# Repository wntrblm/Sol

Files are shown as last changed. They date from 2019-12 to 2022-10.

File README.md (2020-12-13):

# Winterbloom Sol

Winterbloom Sol is an open-source Eurorack module. You can find out more at https://wntr.dev/sol.

## License and contributing

The code here is available under the [MIT License](firmware/LICENSE), the hardware designs are available under [CC-BY-SA 4.0](hardware/LICENSE). I welcome contributors, please read the [Code of Conduct](CODE_OF_CONDUCT.md) first. :)

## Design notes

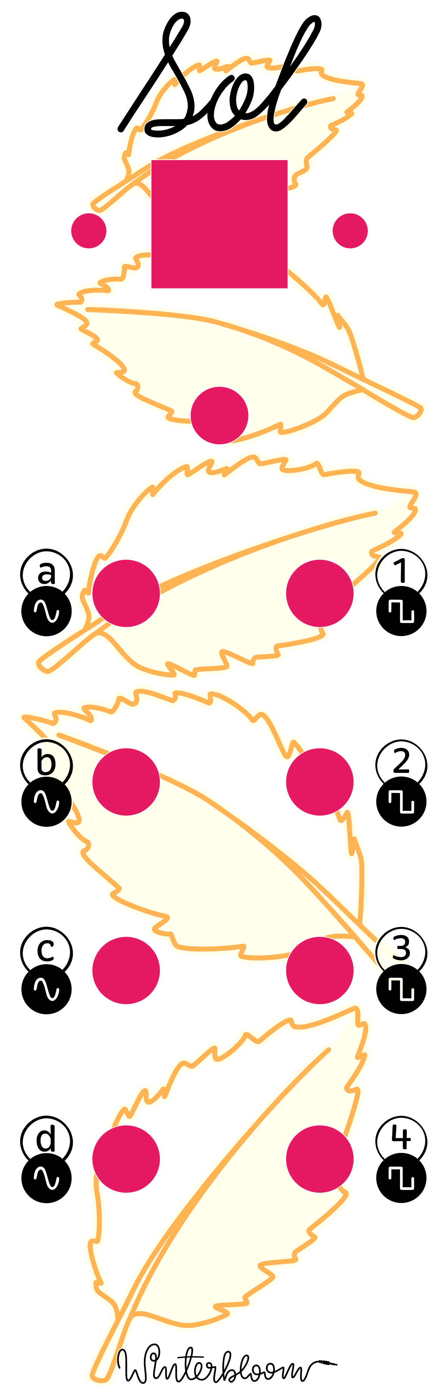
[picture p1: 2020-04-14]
hardware/rev1/panel/panel-texture.png

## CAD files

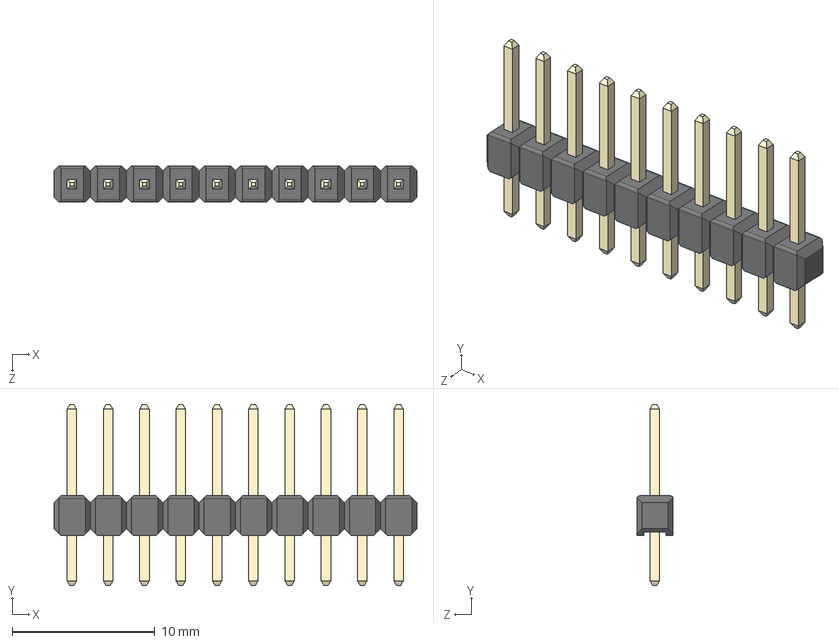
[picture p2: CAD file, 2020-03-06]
hardware/rev1/jackboard/3dmodels/pin-header-1x10-male.step
25.4 x 12.7 x 2.54 mm
holder
pin x 10

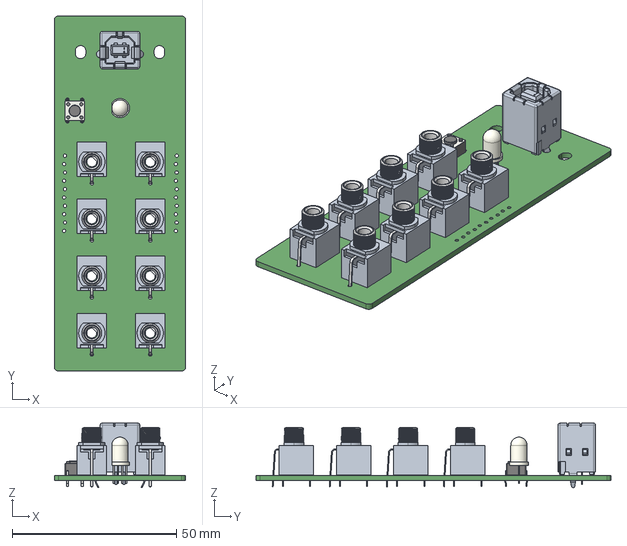
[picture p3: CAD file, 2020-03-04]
hardware/rev1/jackboard/jackboard.step
40.0 x 108.0 x 19.6 mm

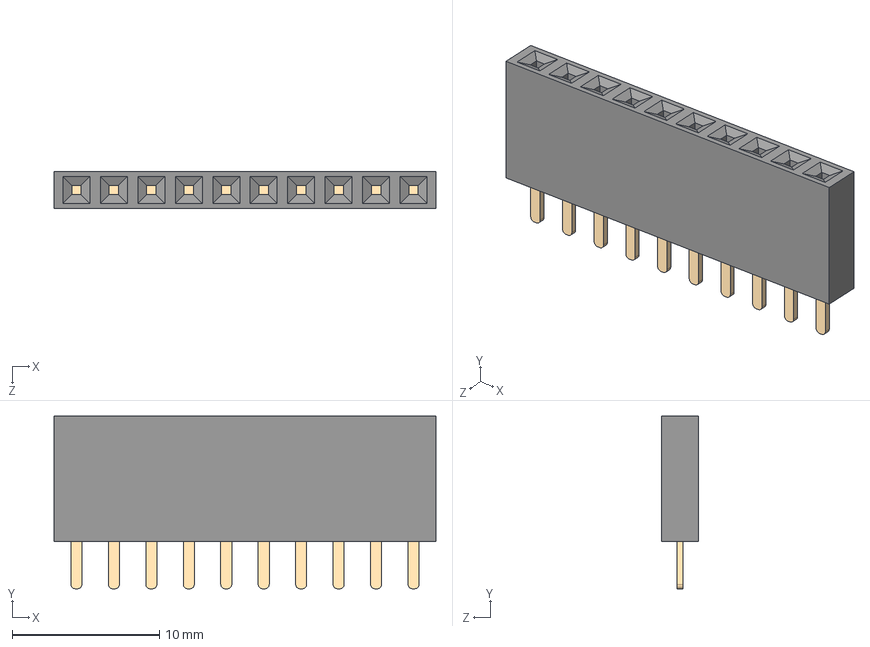
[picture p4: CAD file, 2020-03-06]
hardware/rev1/mainboard/3dmodels/pin-header-1x10-female.step
25.9 x 11.7 x 2.54 mm

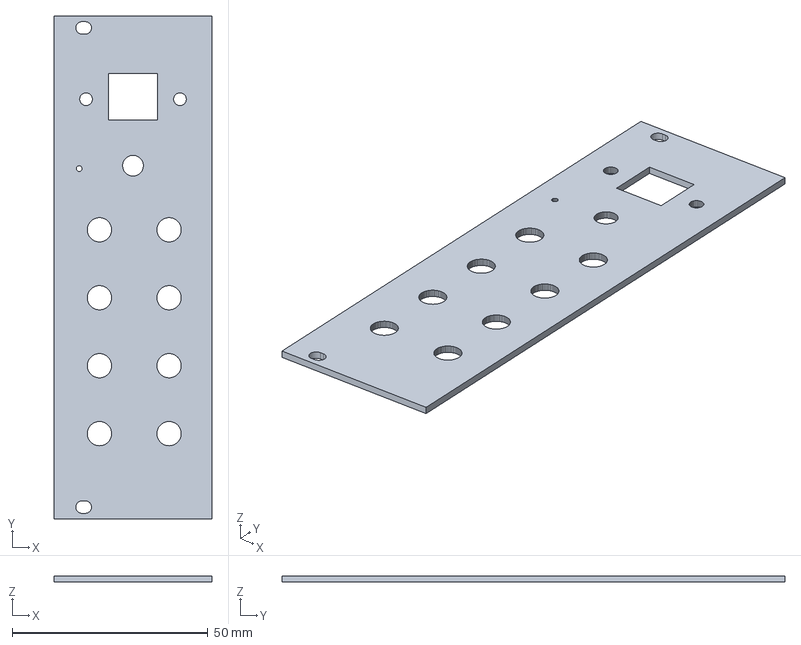
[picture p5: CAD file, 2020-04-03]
hardware/rev1/panel/panel.step
40.3 x 128.5 x 1.60 mm

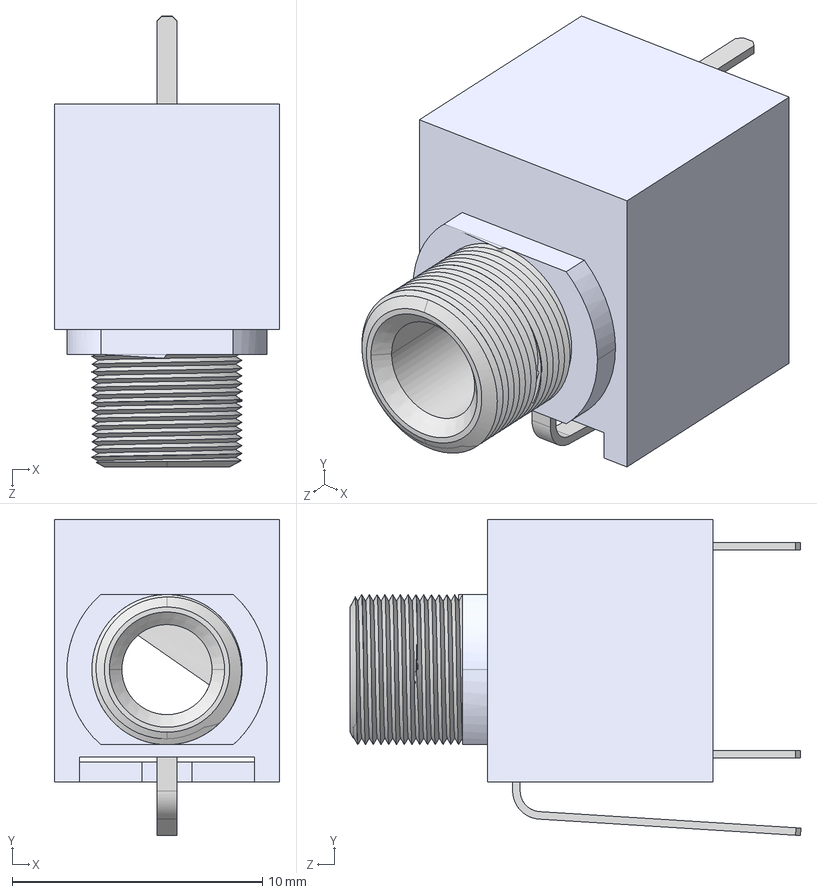
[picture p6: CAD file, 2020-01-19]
hardware/rev1/programming-board/3dmodels/User Library-PJ301M-12 Thonkiconn v0_2.STEP
9.00 x 12.6 x 18.0 mm

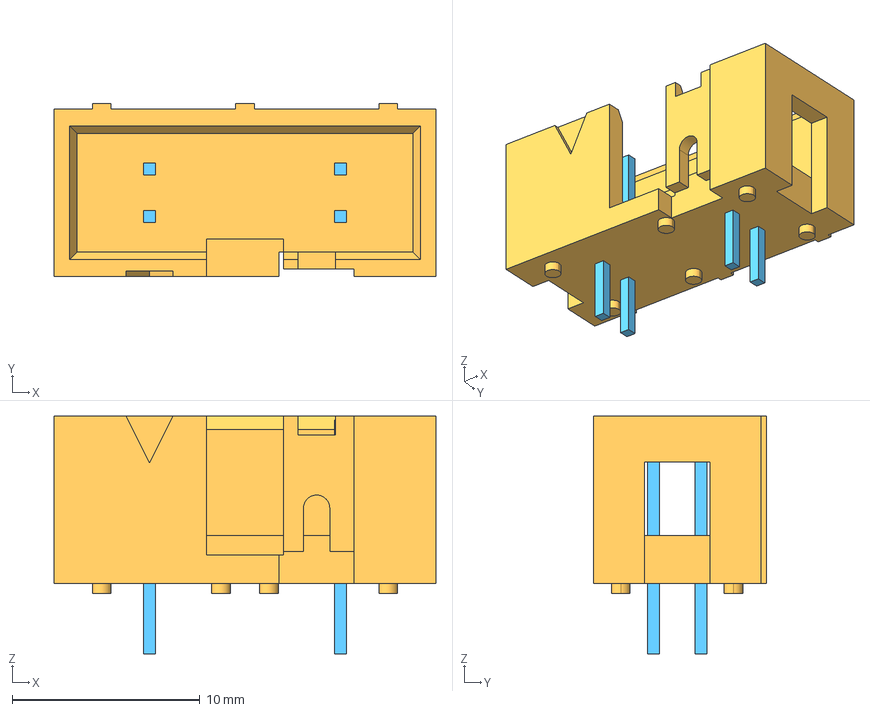
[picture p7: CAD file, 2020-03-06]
hardware/rev1/mainboard/3dmodels/eurorack-power.step
20.3 x 9.20 x 12.6 mm

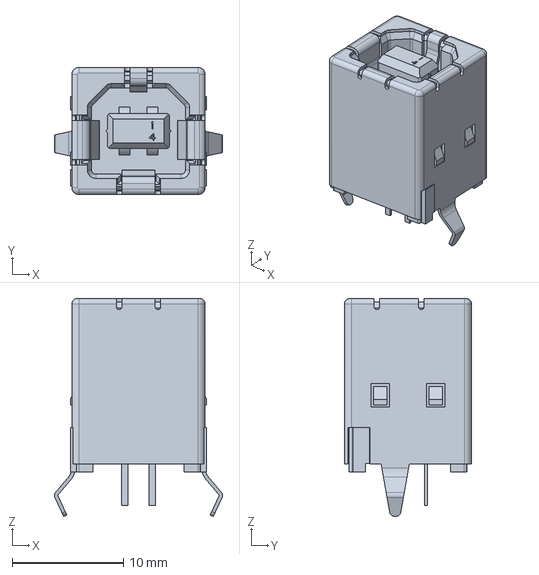
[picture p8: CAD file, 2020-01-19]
hardware/rev1/programming-board/3dmodels/c-5787834-1-c-3d.step
15.1 x 11.5 x 19.6 mm

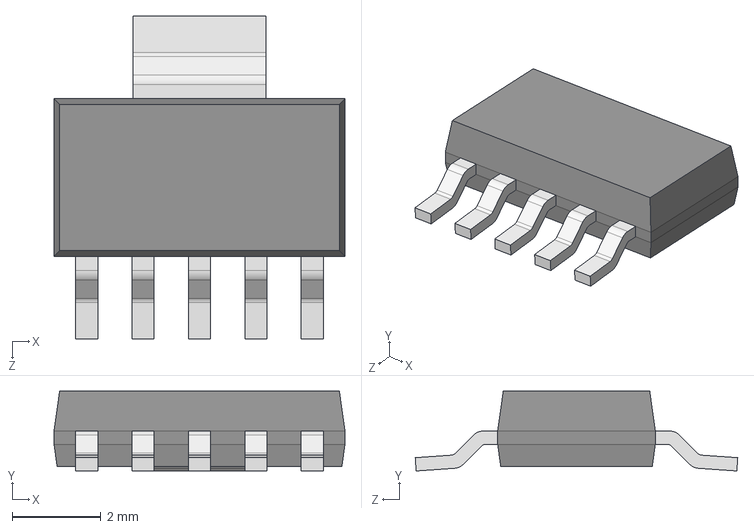
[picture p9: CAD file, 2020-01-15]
hardware/rev1/mainboard/3dmodels/sot223-6.step
6.55 x 1.80 x 7.26 mm

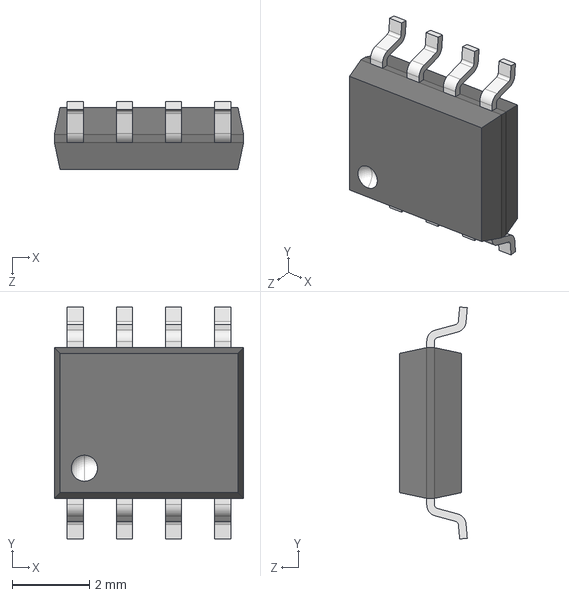
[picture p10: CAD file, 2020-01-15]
hardware/rev1/mainboard/3dmodels/soic-8.step
4.90 x 6.00 x 1.75 mm

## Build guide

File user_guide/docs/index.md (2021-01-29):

# Winterbloom Sol User Guide

Sol is a uniquely customizable USB MIDI to CV/Gate module. It's designed to be useful right out of the box but flexible enough to accommodate a ton of different CV/Gate generation needs. It's meant to be useful to newcomers, deeply experienced Eurorack enthusiasts, and most in between. With four CV outs and four gate outputs, it can perform all sorts of tasks for your Eurorack synthesizer.

## Getting support and help

We want you to have a wonderful experience with your module. If you need help or run into problems, please reach out to us. Email is the best way for product issues, whereas Discord and GitHub are great for getting advice and help on how to customize your module.

* Send us [an email](mailto:support@winterbloom.com).
* File a bug [on GitHub](https://github.com/theacodes/Winterbloom-Sol)
* Reach out on the [Discord][discord]

## Installing the module

To install this into your Eurorack setup:

1. Connect a Eurorack power cable to your power supply and the back of the module. **Note that even though the power connector on the module is keyed, double check that the red stripe is on the side labeled `red stripe`!**
1. Screw the module to your rack's rails.
1. Connect a USB cable to the USB connector on the front of the module and to your computer.

You should see a drive named `CIRCUITPY` on your computer at this point. If not, please reach out to us! You should also see a MIDI device named `Sol Audio`. The LED on the front of the module should temporarily flash yellow and red before turning light blue- light blue means all is well.

## Connecting via MIDI

Once the module is installed and connected to your computer, you should see a MIDI device named `Sol Audio`. You can use this as a MIDI output in your DAW of choice, but here's some pointers for some common ones:

In **Ableton Live**, you'll need to enable *Track* and *Sync* for `Sol Audio` output in *Preferences > MIDI.*

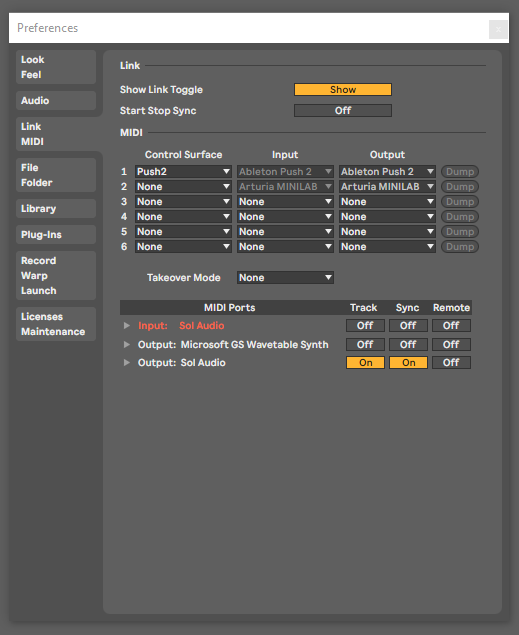
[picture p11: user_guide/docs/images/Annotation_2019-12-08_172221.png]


If you don't enable *Sync*, Live won't send MIDI clock data.

If you're using **Orca**, it should automatically detect Sol. Make sure the MIDI output device says `Sol Audio`

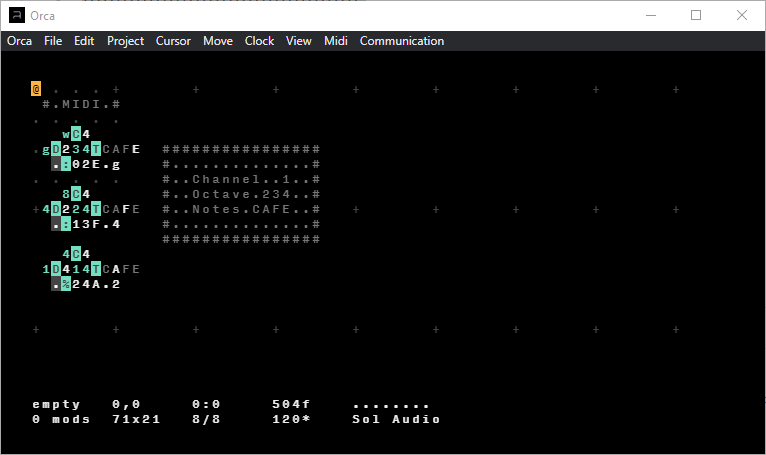
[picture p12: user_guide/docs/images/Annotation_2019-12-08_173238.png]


Sol works out of the box with **JACK** on Linux, as an Advanced LSA MIDI device.
If your DAW uses JACK MIDI rather than ALSA MIDI, you will need to install `a2jmidid`:

```bash
$ sudo apt install a2jmidid
```

Then, enable it in your JACK settings:

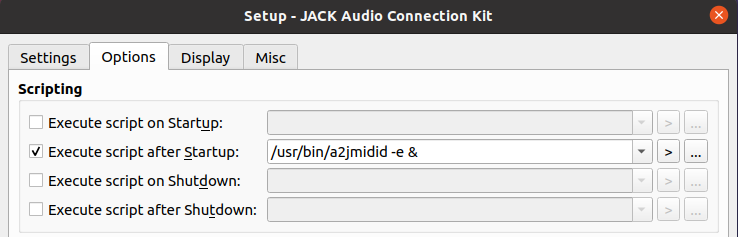
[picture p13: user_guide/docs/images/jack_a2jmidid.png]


Now Sol will appear as a MIDI device under the JACK MIDI panel, and you can easily connect your DAW and other MIDI devices.
Sol will still work as an Advanced LSA MIDI device for use with, for instance, ORCA.

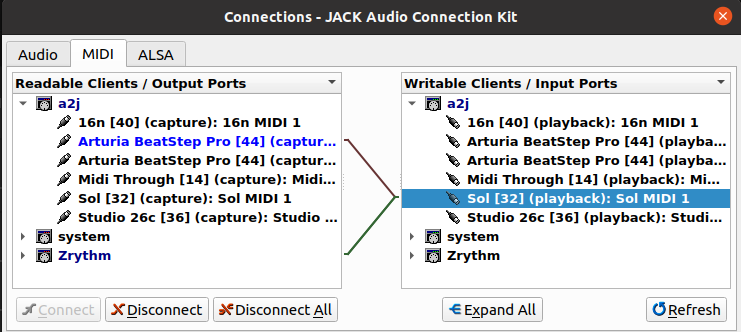
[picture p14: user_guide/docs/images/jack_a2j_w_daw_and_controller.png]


## Making your first connections

Sol has eight outputs. Four are continuous CV outputs and the other four are gate/trigger outputs:

- **CVs A, B, C, & D**: -5 to +8v.
- **Gates 1, 2, 3, & 4**: Gate/trigger 0 or 5v.

These outputs can be used by the program on the module to serve various functions. The default program uses the outputs as follows:

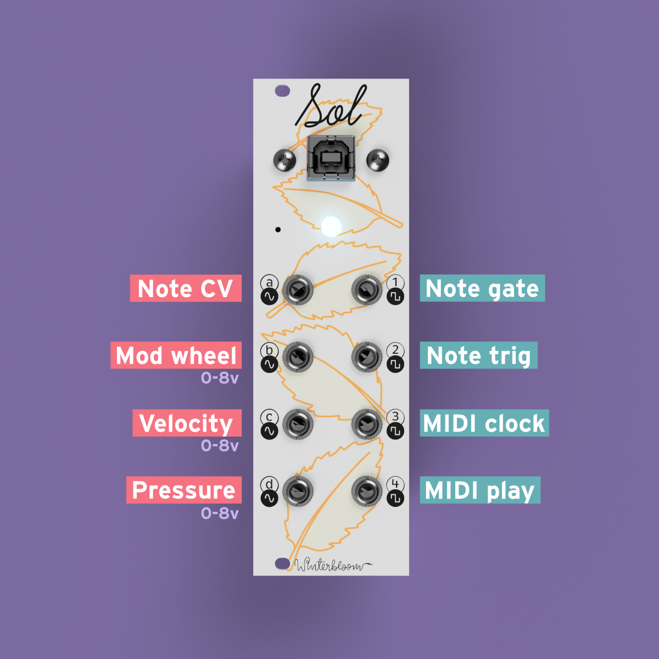
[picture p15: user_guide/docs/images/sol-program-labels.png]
images/sol-program-labels


- **CV A**: Note pitch (1v/Octave)
- **CV B**: Mod wheel (0 to 8v)
- **CV C**: Note velocity  (0 to 8v)
- **CV D**: Channel pressure (0 to 8v)
- **Gate 1**: Note gate (w/ re-triggering)
- **Gate 2**: Note trigger
- **Gate 3**: MIDI transport (high when playing, low when paused/stopped)
- **Gate 4**: MIDI clock (emits a pulse for every 8th note)

Let's try these out! Connect `CV A` (the note pitch CV) to the V/Oct input of an oscillator. If you have an ADSR/Envelope generator, connect `Gate 1` (the note gate) to its input. If you don't, just connect the output of the oscillator to your output module.



Now, using your DAW of choice, play some MIDI notes. You should see the LED on the front of the module change as it receives MIDI data and it should, of course, make some lovely sounds through your oscillator (and envelope generator, if you have one). Congrats, you've made your first connections! 🎉

If things aren't working right now, reach out! Nothing else in this guide will work if this part isn't working!

Now, if you have a filter, connect your oscillator through the filter and connect `CV B` (the mod wheel CV) to the filter's frequency CV input.



Now, while playing some notes try using the mod wheel. You should see the mod wheel change the filter frequency. Try it with the other CV outputs as well! `CV C` is the note velocity and `CV D` is the channel pressure.

Congrats! You now know how the default program works! 🎉

## Modifying the program

Now that you know the basics it's time to get familiar with customizing the program that's running on Sol.

Sol should show up both as a MIDI output device **and** a small external drive named `CIRCUITPY`. In that drive, you should find a file named `code.py`. Sol runs [CircuitPython][CircuitPython] which means that its firmware is written in the approachable [Python](https://python.org) programming language and you don't need any special knowledge or compilers to make changes to it. So, open up that file in your favorite text editor, we're going to make some changes!

If you don't have a text editor - that's okay! While you could use Notepad (Windows) or TextEdit (Mac), these can sometimes have issues with CircuitPython devices like Sol. I'd recommend [installing Mu](https://learn.adafruit.com/welcome-to-circuitpython/installing-mu-editor) if you're new to this whole world. You can read more about editing code for CircuitPython in [Adafruit's guide](https://learn.adafruit.com/welcome-to-circuitpython/creating-and-editing-code).

In the `code.py` you should see a line that looks like this:

```python
outputs.cv_a = sol.voct(state)
```

Modify this line so that it reads:

```python
outputs.cv_a = sol.voct(state) - 1.0
```

!!! warning "Be careful"
    Python is *whitespace-sensitive*. That means tabs and spaces are important! Make sure that you don't accidentally change the indentation level of this line.

This change subtracts 1 volt from the note CV output. So, it should make it sound as if all notes are played one octave lower. **Save the file**. You should notice the module "reboot" - it may flash green and red for a second but after it should settle back into its idle state with the LED showing a light blue color.

Once it's settled, try playing notes again. You should notice that they're an octave lower.

If you see the module flashing yellow/red, see the section below on finding problems or reach out!

**Congrats**, you've made your first change to how the module works!  🎉

This might seem like a trivial change (and it is!) but it's meant to show how customization works on this module. You just edit a file and save - there is no need for custom compilers, complicated software, or even experience with programming.

As a next challenge, you can change the mod wheel output (`CV B`) to be -5v to +5v instead of the default 0 to 8v!

I encourage you to read through [the example programs](#included-example-programs), [the various inputs and outputs](#about-the-state-and-outputs), [the default program](https://github.com/theacodes/Winterbloom-Sol/blob/master/examples/1_default.py), and [learn more about CircuitPython](https://learn.adafruit.com/welcome-to-circuitpython/overview) so you can get the most of your module. Also, please come chat on the [Discord][discord] where you can ask questions and see what others are doing with their Sol!

## Help! This thing isn't working and it's blinking at me!

If it's blinking at you that means there's some sort of error in the program. Don't worry, you can get it figured out.

If you connect using the [serial console](https://learn.adafruit.com/welcome-to-circuitpython/kattni-connecting-to-the-serial-console) you should be able to see the error. If you don't see it right away, you might need to reset the board (either by pressing the little button on the bottom of the module or power cycling your synth). Sometimes you can press `Ctrl+C` followed by `Ctrl+D` in the serial console to get the board to reset and tell you the error.

In any case, reach out on [Discord][discord] and we can walk you through figuring out what went wrong.

## Included example programs

There are several included example programs to learn from and use. If you want to use these, copy their contents to `code.py` on the `CIRCUITPY` drive. **Be sure to save it as the correct name,** if you don't name it `code.py` it won't change anything. If you want to restore the original `code.py` it is [here](https://github.com/theacodes/Winterbloom-Sol/blob/master/examples/1_default.py).

1. [Slew limiter example](https://github.com/theacodes/Winterbloom-Sol/blob/master/examples/2_slew_limiter.py): Shows how to use a `SlewLimiter` to introduce legato.
1. [ADSR example](https://github.com/theacodes/Winterbloom-Sol/blob/master/examples/3_adsr.py): Shows how to use one of the CV outputs as an ADSR envelope generator.
1. [Clocks example](https://github.com/theacodes/Winterbloom-Sol/blob/master/examples/4_clocks.py): Shows how to use the MIDI clock to output trigger pulses at various note markers.
1. [LFO example](https://github.com/theacodes/Winterbloom-Sol/blob/master/examples/5_lfo.py): Shows how to use Sol's built in LFO generators.
1. [Polyphony example](https://github.com/theacodes/Winterbloom-Sol/blob/master/examples/6_poly.py): Shows how to use Sol's `Poly` helper to output CV & gate for multiple notes at once.
1. [Random](https://github.com/theacodes/Winterbloom-Sol/blob/master/examples/7_random.py): Shows how to use Sol as a random modulation source.
1. [The default program](https://github.com/theacodes/Winterbloom-Sol/blob/master/examples/1_default.py): As mentioned above, this handles the basic use case of outputting note CV, note gate, mod wheel CC, and some MIDI clock and transport gates. It's fairly complicated compared to the other examples here, so we recommend starting with some of the other examples as they tend to be a bit easier to digest.

## About the state, outputs, and helper functions

The `loop` function gets called with three parameters:

- `last` the previous `state`.
- `state` the current state.
- `outputs` the outputs.

As you get deeper into customizing your module, you might wonder what all is available from the `state` and `output` objects in the loop.

The [**State** objects](https://github.com/theacodes/Winterbloom-Sol/blob/master/firmware/winterbloom_sol/sol.py#L36) lets you take a look at the MIDI state, it has the following properties:

- `state.note` and `state.latest_note` which both give the most recent note played. For example, if middle C was the last note played it will be `60`. If no note is played, it'll be `None`.
- `state.oldest_note` gives the oldest note being played.
- `state.lowest_note` gives the lowest note being played.
- `state.highest_note` gives the highest note being played.
- `state.cc(number)` gives the value of the MIDI continuous controller. For example, to get the mod wheel you'd use `state.cc(1)` . The value is from `0.0 - 1.0`.
- `state.velocity` gives the velocity value of the most recent note. The value is from `0.0 - 1.0`.
- `state.pressure` gives the channel pressure. The value is from `0.0 - 1.0`.
- `state.pitch_bend` gives the pitch bend amount. The value is from `0.0 - 1.0`.
- `state.playing` is `True` if the MIDI transport is playing, and is `False` if it's paused or stopped.
- `state.clock` gives the count of MIDI clocks received. There are 24 MIDI clocks per quarter note. Take a look at the `should_trigger_clock` helper function as well.
- `state.clock_frequency` gives you the BPM for the MIDI clocks.
- `state.message` gives you direct access to the last MIDI message received (see below).

The [**Outputs** object](https://github.com/theacodes/Winterbloom-Sol/blob/master/firmware/winterbloom_sol/sol.py#L179) lets you control the output jacks. It has the following properties:

- `outputs.cv_a`, `outputs.cv_b`, `outputs.cv_c`, `outputs.cv_d` are the CV outputs. You can set it to a number between `-5.0` and `8.0`. This is in volts. Setting `outputs.cv_a = 5.0` will output 5v on CV A.
- `outputs.set_cv(output, value)` sets the given CV output to the given value, just like using `outputs.cv_a` et. al. Calling `outputs.set_cv("a", 5.0)` will output 5v on CV A.
- `outputs.gate_1`, `outputs.gate_2`, `outputs.gate_3`, and `outputs.gate_4` are the gate outputs. They can be `True` or `False`. Setting to `True` will output 5v on that gate, setting to `False` will output 0v on that gate.
- `outputs.set_gate(output, value)` sets the given gate output to the given value (`True` or `False`.)
- `outputs.trigger_gate_1()`, etc. are helper methods to send trigger pulses through one of the gate. Calling this will cause the gate to be `True` for a short period of time before returning to `False`.
- `outputs.trigger_gate(output)` triggers the given gate output just like `outputs.trigger_gate_1()` and friends.
- `outputs.retrigger_gate_1()`, etc. are helper methods to "retrigger" one of the gate outputs. Calling this will cause the gate to go `False` for a short period of time before returning to `True`.
- `outputs.retrigger_gate(output)` retriggers the given gate output just like `outputs.retrigger_gate_1()` and friends.

Sol also has several helper methods that can be used for common tasks:

- `sol.note_to_volts_per_octave(note)` returns the volts for a give MIDI note name. For example `sol.note_to_volts_per_octave(60)` will give `3.0`.
- `sol.offset_for_pitchbend(pitch_bend, range)` will give a pitch bend volt offset for the given pitch bend value. For example, if you want your pitch bend to give you 1 octave of range up and down, you'd do something like `outputs.cv_a = sol.note_to_volts_per_octave(state.note) + sol.offset_for_pitchbend(state.pitch_bend, range=1.0)`
- `sol.voct(state)` combines the above two helpers into one convenient helper that returns a voltage for the given state's note and also takes pitch bend into account.
- `sol.was_key_pressed(state)` returns `True` is a new note was pressed.
- `sol.should_trigger_clock(state, division)` return `True` if the clock matches the note division. For example, `sol.should_trigger_clock(state, 1/16)` will return `True` once for every sixteenth note.
- `sol.map(value, low, high, new_low, new_high)`: re-maps a value to a different range. For example, `sol.map(0.5, 0.0, 1.0, 0.0, 10.0)` will return `5.0`.

The [**MIDI** message object](https://github.com/theacodes/Winterbloom_SmolMIDI/blob/master/winterbloom_smolmidi.py#L79) contains just three fields:

- `message.type`, the type of the message. SmolMIDI provides several MIDI message types, such as `smolmidi.NOTE_ON` and `smolmidi.CC`.
- `message.channel`, the channel on to which the message is associated, or `None` if not applicable. Note that, unlike in most higher-level MIDI applications, this value is zero-indexed; `message.channel == 0` means what most applications
call channel 1.
- `message.data`, a byte array of the data transmitted with the message. For example, a `NOTE_ON` message's data is a single byte representing the note being turned on, which can be used with the note to V/Oct helper: `sol.note_to_volts_per_octave(message.data[0])`.

## Updating the firmware

Updating the firmware requires two steps: Updating CircuitPython and updating Sol's libraries.

### Updating CircuitPython

1. [Download the latest version of CircuitPython for Winterbloom Sol](https://circuitpython.org/board/winterbloom_sol/).
2. Place Sol in bootloader mode by pressing the reset button twice quickly. The reset button is located under the panel to the left of the LED. There is a small hole in the panel that you can use a paperclip to press the button if needed. Once in bootloader mode, you should see a drive on your computer named `SOLBOOT`.
3. Copy the `uf2` file from step 1 to the `SOLBOOT` drive. Sol should restart by itself.

### Updating Sol's libraries

1. [Download the latest release bundle for Sol](https://github.com/theacodes/Winterbloom-Sol/releases).
2. Unzip the release bundle, and then copy the contents to Sol's `CIRCUITPY` drive, replacing any existing files.
3. Reboot Sol by power cycling your synthesizer or pressing the reset button again.

## Restoring lost calibration

Sol is calibrated during manufacturing and we keep a copy of your factory calibration in case it gets lost. If your module is in panic mode and says that it has lost its calibration then this can help. Please connect your module via USB, open this page in Chrome, and click the button below. If this doesn't work, please [reach out to us](#getting-help-and-support).

<button id="restore-connect-button" type="button">🔌 Connect</button>
<pre id="restore-output"></pre>
<script src="calibration_restore.js" type="module"></script>

!!! warning
    This is based on pretty experimental web technology so it might not work the first time. Try it a few times and see if it works, if not, reach out to us.

## Frequently asked questions

Got a question not answered here? [Reach out](#getting-support-and-help), we'll be happy to help!

### Can Sol be used as a MIDI Host? Can I connect a USB MIDI device directly to Sol?

Since Sol is re-programmable and we imagined that most folks would use it attached to a computer, we didn't include this functionality - especially since it would cost more money. However, if you want to go "computerless" you can use a Raspberry Pi as your MIDI host. There's an excellent video from [Blitz City DIY on using the Raspberry Pi as a MIDI host](https://www.youtube.com/watch?v=LMDs44wQaK0).

### Does Sol support MIDI 2.0?

Not *yet*. We're waiting to get our hands on hardware and software that support MIDI 2.0 so we can add it to Sol. As far as we know, there's no reason we won't be able to add this via a firmware update. If you're interested in helping out, please [reach out](#getting-support-and-help).

### Can Sol output audio on its CV outputs?

Not with the default CircuitPython-based firmware. CircuitPython is designed to be approachable and easy to use, but it comes at the cost of not being as fast as firmware written in C/c++. If you're feeling super brave, Sol is completely open source so you could write your own firmware in C/C++ and do whatever you'd like. Sol's hardware is very similar to the [Adafruit Feather M4 Express](https://learn.adafruit.com/adafruit-feather-m4-express-atsamd51), so you should be able to use resources for that as a starting point. The hardware uses a DAC that can do 1MSPS, so in theory it could output at audio rate.

## Open source hardware & software

Sol is completely open source and hacking is encouraged.

* The [firmware](https://github.com/theacodes/Winterbloom_Sol/tree/master/firmware) is available under the [MIT License](https://github.com/theacodes/Winterbloom_Sol/blob/master/firmware/LICENSE).
* The [hardware design](https://github.com/theacodes/Winterbloom_Sol/tree/master/hardware/rev1) is available under the [CC BY-SA 4.0 License](https://github.com/theacodes/Winterbloom_Sol/blob/master/hardware/LICENSE) and is designed using [KiCAD](https://kicad.org/) which is free and open-source. You can open the hardware files using KiCAD or you can check out a [PDF of the schematic](https://github.com/theacodes/Winterbloom_Sol/raw/master/hardware/rev1/mainboard/mainboard.pdf).
* [CircuitPython][CircuitPython] is available under the [MIT License](https://github.com/adafruit/circuitpython/blob/main/LICENSE).

Open Source Hardware Association mark Sol is [certified open source hardware](https://certification.oshwa.org/us001030.html).

## Acknowledgments and thanks

Sol would not be possible without support from the following people:

- Scott Shawcroft
- John Edgar Park
- Scotland Symons
- Echo Harker
- Andi McClure

Sol would also not be possible without the help of the CircuitPython community and Adafruit Industries.

[CircuitPython]: https://circuitpython.org
[discord]: https://discord.gg/UpfqghQ

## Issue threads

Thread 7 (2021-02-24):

Default program's clock out can cause multiple triggers for each note at slower clocks

theacodes, 2021-02-24:
Since `state.clock` can remain the same value between subsequent calls to `loop`, if the clock is slow enough loop will actually retrigger the output multiple times for a single clock.

A possible fix is to make it possible to "latch" `Trigger`/`Retrigger` objects - preventing them from triggering again until `unlatched`.

Another possible fix is to make `helpers.should_trigger_clock` memoize the last `state.clock` value that it returned `True` for and return `False` if it sees it again.

jmcneil86043, 2021-04-28:
I’d like to vote for this issue to be fixed. I was going to write up the bug myself but just found this. The double trigger makes the clock unusable for things like a tap input for a delay. Otherwise I love Sol. It is a perfect companion for my Deluge.

theacodes, 2021-04-28:
Hey folks, would one of you be willing to try out this code and see if it fixes the issue for you?

You'll need to:

1. Unzip the files
2. Copy them to your `CIRCUITPY` drive, replacing any existing files
3. Power cycle your device

[sol-2021.3.28.zip](https://github.com/wntrblm/Sol/files/6393368/sol-2021.3.28.zip)

joehillaintdead, 2021-04-29:
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

I've loaded this and sent MIDI. Sol sends one clock pulse on gate 3 and then goes into blinky mode:
7 yellow, 4 magenta

from the serial console:
`
code.py output:
Traceback (most recent call last):
  File "code.py", line 84, in <module>
  File "/lib/winterbloom_sol/__init__.py", line 41, in run
  File "/lib/winterbloom_sol/sol.py", line 370, in run
  File "/lib/winterbloom_sol/sol.py", line 368, in run
  File "code.py", line 75, in loop
  File "/lib/winterbloom_sol/helpers.py", line 69, in should_trigger_clock
AttributeError: 'NoneType' object has no attribute 'type'

Code done running.`

theacodes, 2021-04-29:
Ah, I see what went wrong. Can you give this one a try when you get a chance?

[sol-2021.4.29.zip](https://github.com/wntrblm/Sol/files/6399072/sol-2021.4.29.zip)

jmcneil86043, 2021-04-30:
This works for me!! Nice clean pulses. I tried it at 16th and 1/4 notes at a wide range of BPM
Thank you for the quick fix!

theacodes, 2021-04-30:
Thanks for testing! This has now been released: https://github.com/wntrblm/Sol/releases/tag/2021.4.30

Closed 2021-04-30.

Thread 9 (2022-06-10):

Non-functional after upgrading to CircuitPython 7.30

shakfu, 2022-06-10:
I recently updated Sol to [CircuitPython 7.30](https://circuitpython.org/board/winterbloom_sol/) and after doing so, the module stopped working (blinking green light) and after installing Mu, and opening a serial console, importing `code.py`, it turned out that the `.mpy` format changed from CircuitPython versions 6 to 7

I used the `circup` python module to check which ones needed to be updated and two modules: adafruit_bus_device and neopixel needed to be updated, and I went ahead.

After restarting, there were still green flashing lights and I opened code.py on Mu and tried to run it and it gave the following error:

```python
Auto-reload is on. Simply save files over USB to run them or enter REPL to disable.
code.py output:
Traceback (most recent call last):
  File "code.py", line 84, in <module>
  File "/lib/winterbloom_sol/__init__.py", line 40, in run
  File "/lib/winterbloom_sol/sol.py", line 292, in __init__
  File "/lib/winterbloom_sol/sol.py", line 187, in __init__
  File "/lib/winterbloom_ad_dacs/_common.py", line 126, in soft_reset
  File "/lib/winterbloom_ad_dacs/_common.py", line 122, in send_command
AttributeError: 'SPIDevice' object has no attribute 'spi'
```

I checked the call in `_common.py` line 115:

```python
spi_device = SPIDevice(spi, cs_io, polarity=0, phase=1, baudrate=5000000)
```

There doesn't seem to be a problem as the interface hasn't changed much:

```python

# new version of spi_device.py
# https://github.com/adafruit/Adafruit_CircuitPython_BusDevice/blob/main/adafruit_bus_device/spi_device.py
def __init__(self, spi: SPI, chip_select: Optional[DigitalInOut] = None, *,
        cs_active_value: bool = False,
        baudrate: int = 100000,
        polarity: int = 0,
        phase: int = 0,
        extra_clocks: int = 0
    ) -> None:
        self.spi = spi
        self.baudrate = baudrate
        self.polarity = polarity
        self.phase = phase
        self.extra_clocks = extra_clocks
        self.chip_select = chip_select
        self.cs_active_value = cs_active_value
        if self.chip_select:
            self.chip_select.switch_to_output(value=True)

# old version used spi_device.py
# https://github.com/adafruit/Adafruit_CircuitPython_BusDevice/blob/cf7eabc4fa079a1443f548aed8ee2966af9b5fc1/adafruit_bus_device/spi_device.py
def __init__(self, spi, chip_select=None, *,
                 baudrate=100000, polarity=0, phase=0, extra_clocks=0):
        self.spi = spi
        self.baudrate = baudrate
        self.polarity = polarity
        self.phase = phase
        self.extra_clocks = extra_clocks
        self.chip_select = chip_select
        if self.chip_select:
            self.chip_select.switch_to_output(value=True)
```

I'm a bit stuck how to proceed. Can you please advice on what could be the fix, or if it's too much of pain (considering this module is discontinued) can you let me know how to downgrade to make it work again.

Thanks!

shakfu, 2022-06-10:
I downgraded to circuit python 6.3 (`adafruit-circuitpython-winterbloom_sol-en_US-6.3.0.uf2`) and it worked with the last (April 30th 2021 Release). It's working fine now again.

mclainv, 2022-10-16:
> I downgraded to circuit python 6.3 (`adafruit-circuitpython-winterbloom_sol-en_US-6.3.0.uf2`) and it worked with the last (April 30th 2021 Release). It's working fine again.

Do you remember where you found this uf2 file?

shakfu, 2022-10-16:
@mclainv  wrote:
> Do you remember where you found this uf2 file?

Yes, you can get all things related to circuit python and winterbloom sol from the [CircuitPython page for winterbloom sol](https://circuitpython.org/board/winterbloom_sol/).

More specifically, the [file](https://adafruit-circuit-python.s3.amazonaws.com/bin/winterbloom_sol/en_US/adafruit-circuitpython-winterbloom_sol-en_US-6.3.0.uf2) can be downloaded from the Amazon S3 [archive](https://adafruit-circuit-python.s3.amazonaws.com/index.html?prefix=bin/winterbloom_sol/en_US/) linked to on that page.

theacodes, 2022-10-17:
Oh gosh y'all I'm sorry that I've just now seen this issue. I'll take some time this week to make sure that Sol works with the latest CircuitPython.

theacodes, 2022-10-17:
Hey folks, I've published a new release of Sol's firmware and libraries that fixes this. Please update your libraries and let me know if you run into any other issues.

https://github.com/wntrblm/Sol/releases/tag/2022.10.17

shakfu, 2022-10-19:
@theacodes Just tested the fix and it works great. Thanks very much :smile:

theacodes, 2022-10-19:
Wonderful to hear!

On Wed, Oct 19, 2022, 10:12 AM Shakeeb Alireza ***@***.***>
wrote:

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

Closed 2022-10-17.

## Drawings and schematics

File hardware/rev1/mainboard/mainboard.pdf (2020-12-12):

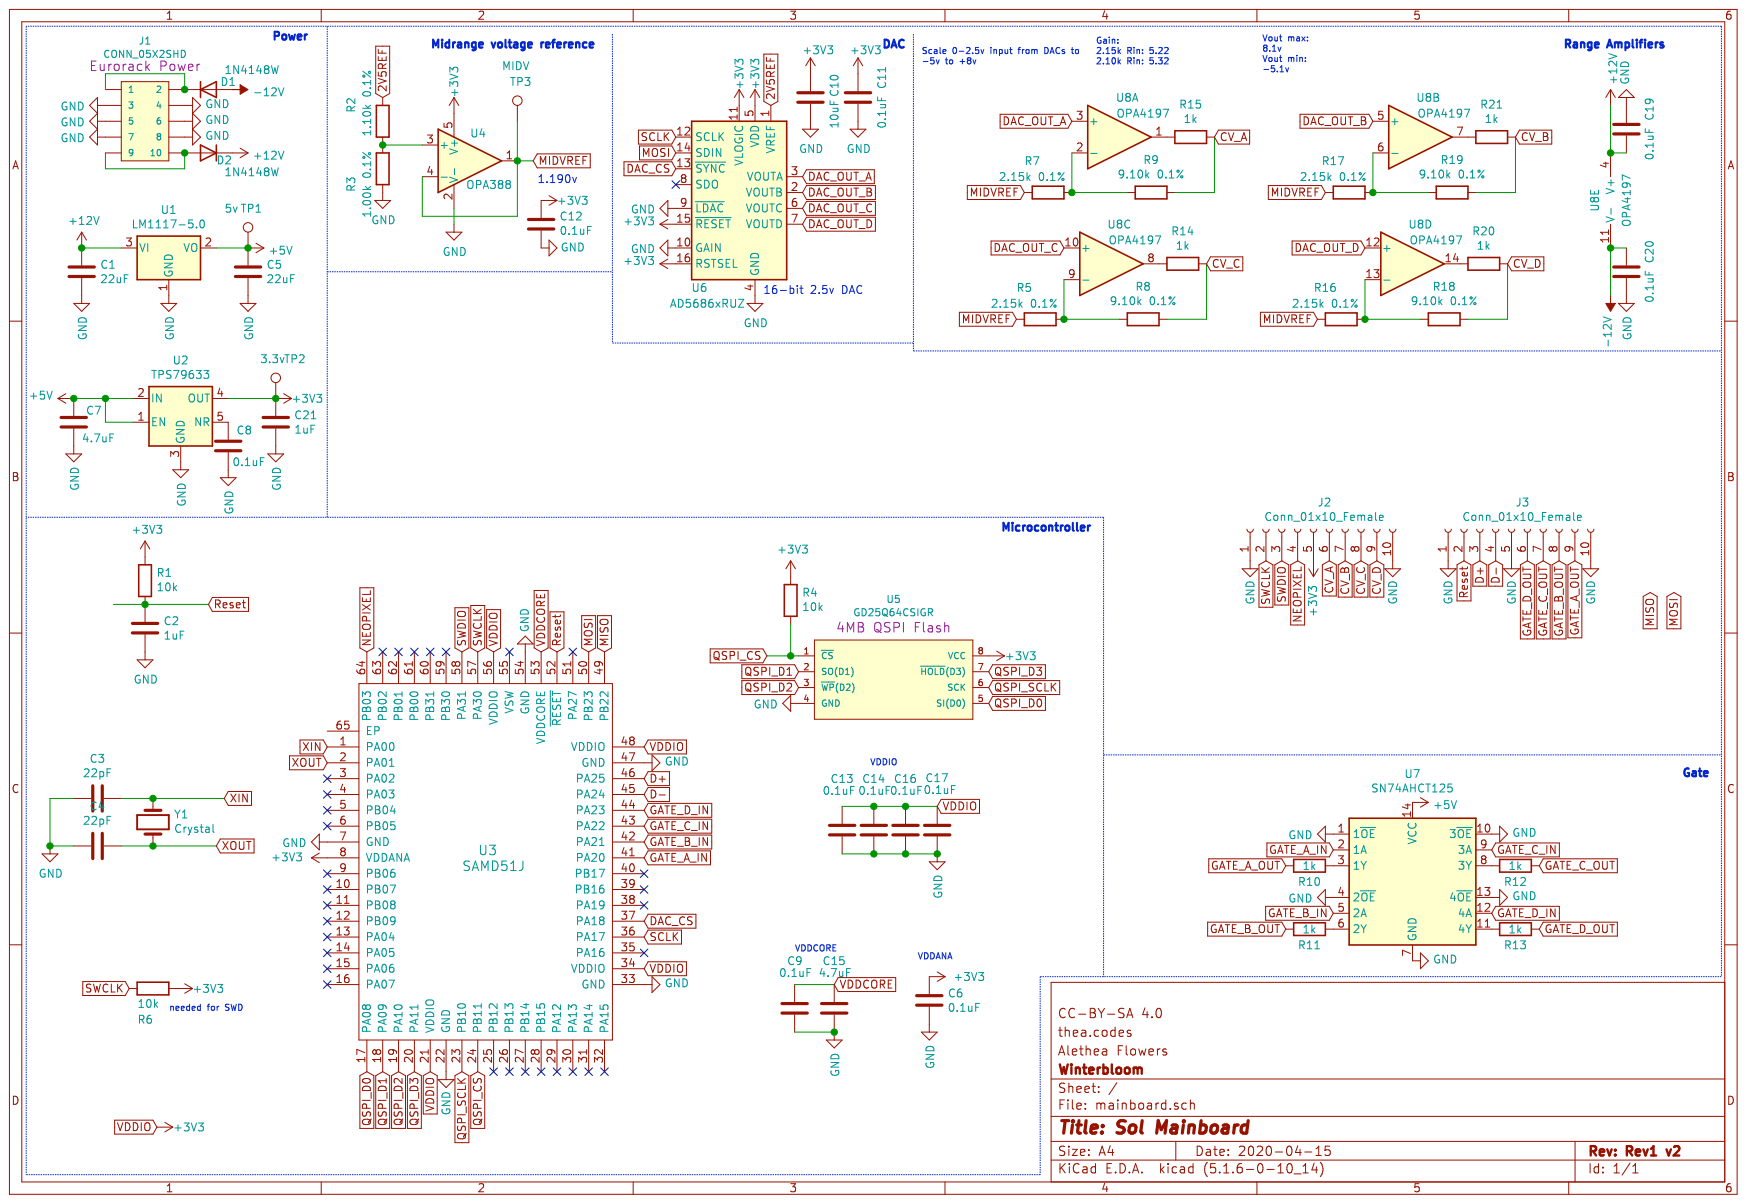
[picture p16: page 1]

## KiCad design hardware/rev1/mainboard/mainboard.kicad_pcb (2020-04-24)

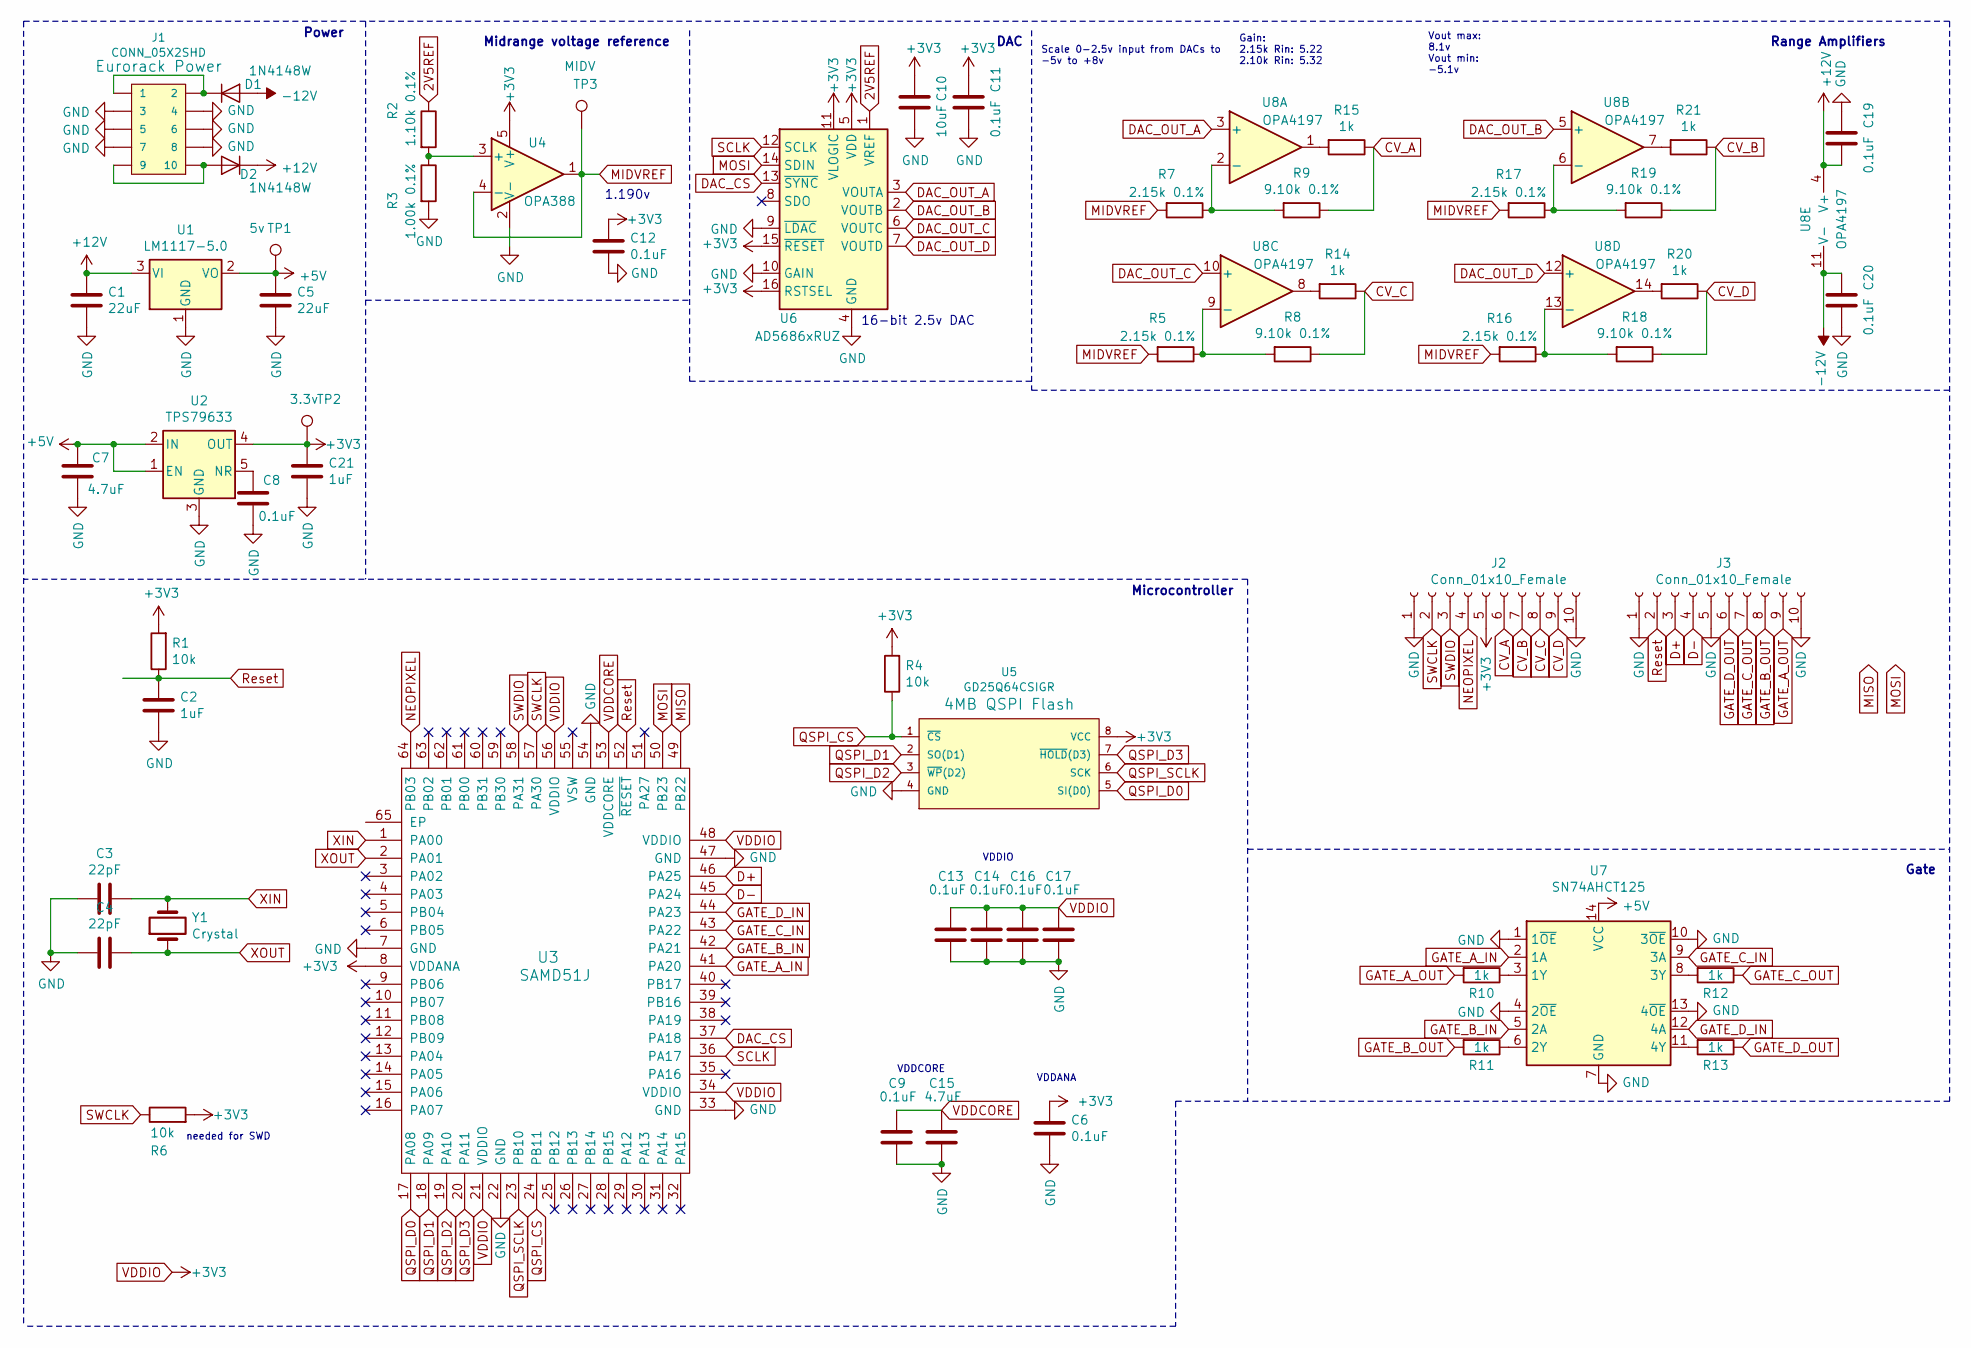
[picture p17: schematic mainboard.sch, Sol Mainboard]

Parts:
C1, C5: 22uF; C_0805_2012Metric_Pad1.15x1.40mm_HandSolder; mpn GRM21BR61E226ME44L
C2, C21: 1uF; C_0603_1608Metric_Pad1.05x0.95mm_HandSolder; mpn MF-CAP-0603-1uF
C3, C4: 22pF; C_0603_1608Metric_Pad1.05x0.95mm_HandSolder; mpn MF-CAP-0603-22pF
C6, C8, C9, C11, C12, C13, C14, C16, C17, C19, C20: 0.1uF; C_0603_1608Metric_Pad1.05x0.95mm_HandSolder; mpn MF-CAP-0603-0.1uF
C7, C15: 4.7uF; C_0805_2012Metric_Pad1.15x1.40mm_HandSolder; mpn GRM21BZ71E475KE15L
C10: 10uF; C_1206_3216Metric_Pad1.42x1.75mm_HandSolder; mpn MF-CAP-1206-10uF
D1, D2: 1N4148W; D_SOD-123; mpn MF-DIO-SOD123-1N4148
J1: CONN_05X2SHD; 2X5-SHROUDED; mpn 61201021621
J2, J3: Conn_01x10_Female; 1X10; mpn MF-CON-2.54mm-01x10
R1, R4, R6: 10k; R_0805_2012Metric_Pad1.15x1.40mm_HandSolder; mpn MF-RES-0805-10K
R2: 1.10k 0.1%; R_1206_3216Metric_Pad1.42x1.75mm_HandSolder; mpn ERA-8AEB112V
R3: 1.00k 0.1%; R_1206_3216Metric_Pad1.42x1.75mm_HandSolder; mpn ERA8AEB102V
R5, R7, R16, R17: 2.15k 0.1%; R_1206_3216Metric_Pad1.42x1.75mm_HandSolder; mpn ERA-8AEB2151V
R8, R9, R18, R19: 9.10k 0.1%; R_1206_3216Metric_Pad1.42x1.75mm_HandSolder; mpn ERA8AEB912V
R10, R11, R12, R13, R14, R15, R20, R21: 1k; R_0805_2012Metric_Pad1.15x1.40mm_HandSolder; mpn MF-RES-0805-1K
TP1: 5v; TestPoint_THTPad_D1.5mm_Drill0.7mm
TP2: 3.3v; TestPoint_THTPad_D1.5mm_Drill0.7mm
TP3: MIDV; TestPoint_THTPad_D1.5mm_Drill0.7mm
U1: LM1117-5.0; SOT-223-3_TabPin2; mpn LM1117IMPX-5.0/NOPB
U2: TPS79633; SOT-223-6_TabPin3; mpn TPS79633DCQR
U3: SAMD51J; TQFP-64_10x10mm_P0.5mm; mpn ATSAMD51J20A-AUT
U4: OPA388; TSOT-23-5_HandSoldering; mpn OPA388IDBVT
U5: GD25Q64CSIGR; SOIC-8; mpn GD25Q64CSIGR
U6: AD5686xRUZ; TSSOP-16_4.4x5mm_P0.65mm; mpn AD5686RBRUZ
U7: SN74AHCT125; TSSOP-14_4.4x5mm_P0.65mm; mpn SN74AHCT125QPWRQ1
U8: OPA4197; TSSOP-14_4.4x5mm_P0.65mm; mpn OPA4197IPWR
Y1: Crystal; Crystal_SMD_2012-2Pin_2.0x1.2mm_HandSoldering; mpn ABS06-32.768KHZ-1-T

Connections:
2V5REF: R2.1, U6.1 (VREF)
+5V: C5.1, C7.1, TP1.1, U1.2 (VO), U2.1 (EN), U2.2 (IN), U7.14 (VCC)
+12V: C1.1, C19.1, D2.1 (K), U1.3 (VI), U8.4 (V+)
-12V: C20.2, D1.2 (A), U8.11 (V-)
CV_A: J2.6, R9.1, R15.1
CV_B: J2.7, R19.1, R21.1
CV_C: J2.8, R8.1, R14.1
CV_D: J2.9, R18.1, R20.1
D+: J3.3, U3.46 (PA25)
D-: J3.4, U3.45 (PA24)
DAC_CS: U3.37 (PA18), U6.13 (~SYNC)
DAC_OUT_A: U6.3 (VOUTA), U8.3 (+)
DAC_OUT_B: U6.2 (VOUTB), U8.5 (+)
DAC_OUT_C: U6.6 (VOUTC), U8.10 (+)
DAC_OUT_D: U6.7 (VOUTD), U8.12 (+)
GATE_A_IN: U3.41 (PA20), U7.2 (1A)
GATE_A_OUT: J3.9, R10.2
GATE_B_IN: U3.42 (PA21), U7.5 (2A)
GATE_B_OUT: J3.8, R11.2
GATE_C_IN: U3.43 (PA22), U7.9 (3A)
GATE_C_OUT: J3.7, R12.1
GATE_D_IN: U3.44 (PA23), U7.12 (4A)
GATE_D_OUT: J3.6, R13.1
GND: C1.2, C2.2, C3.2, C4.2, C5.2, C6.2, C7.2, C8.2, C9.2, C10.2, C11.2, C12.1, C13.2, C14.2, C15.2, C16.2, C17.1, C19.2, C20.1, C21.2, J1.3, J1.4, J1.5, J1.6, J1.7, J1.8, J2.1, J2.10, J3.1, J3.5, J3.10, R3.2, U1.1 (GND), U2.3 (GND), U3.7 (GND), U3.22 (GND), U3.33 (GND), U3.47 (GND), U3.54 (GND), U4.2 (V-), U5.4 (GND), U6.4 (GND), U6.9 (~LDAC), U6.10 (GAIN), U7.1 (1~OE), U7.4 (2~OE), U7.7 (GND), U7.10 (3~OE), U7.13 (4~OE)
MIDVREF: R5.2, R7.2, R16.2, R17.2, TP3.1, U4.1, U4.4 (-)
MISO: U3.49 (PB22)
MOSI: U3.50 (PB23), U6.14 (SDIN)
NEOPIXEL: J2.4, U3.64 (PB03)
unnamed: C8.1, U2.5 (NR)
unnamed: D1.1 (K), J1.1, J1.2
unnamed: D2.2 (A), J1.9, J1.10
unnamed: R2.2, R3.1, U4.3 (+)
unnamed: R5.1, R8.2, U8.9 (-)
unnamed: R7.1, R9.2, U8.2 (-)
unnamed: R10.1, U7.3 (1Y)
unnamed: R11.1, U7.6 (2Y)
unnamed: R12.2, U7.8 (3Y)
unnamed: R13.2, U7.11 (4Y)
unnamed: R14.2, U8.8
unnamed: R15.2, U8.1
unnamed: R16.1, R18.2, U8.13 (-)
unnamed: R17.1, R19.2, U8.6 (-)
unnamed: R20.2, U8.14
unnamed: R21.2, U8.7
QSPI_CS: R4.1, U3.24 (PB11), U5.1 (~CS~)
QSPI_D0: U3.17 (PA08), U5.5 (SI(D0))
QSPI_D1: U3.18 (PA09), U5.2 (SO(D1))
QSPI_D2: U3.19 (PA10), U5.3 (~WP~(D2))
QSPI_D3: U3.20 (PA11), U5.7 (~HOLD~(D3))
QSPI_SCLK: U3.23 (PB10), U5.6 (SCK)
Reset: C2.1, J3.2, R1.1, U3.52 (~RESET)
SCLK: U3.36 (PA17), U6.12 (SCLK)
SWCLK: J2.2, R6.1, U3.57 (PA30)
SWDIO: J2.3, U3.58 (PA31)
VDDCORE: C9.1, C15.1, U3.53 (VDDCORE)
VDDIO: C6.1, C10.1, C11.1, C12.2, C13.1, C14.1, C16.1, C17.2, C21.1, J2.5, R1.2, R4.2, R6.2, TP2.1, U2.4 (OUT), U3.8 (VDDANA), U3.21 (VDDIO), U3.34 (VDDIO), U3.48 (VDDIO), U3.56 (VDDIO), U4.5 (V+), U5.8 (VCC), U6.5 (VDD), U6.11 (VLOGIC), U6.15 (~RESET), U6.16 (RSTSEL)
XIN: C3.1, U3.1 (PA00), Y1.2
XOUT: C4.1, U3.2 (PA01), Y1.1

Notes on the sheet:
Power
Microcontroller
16-bit 2.5v DAC
Midrange voltage reference
1.190v
DAC
Gate
Scale 0-2.5v input from DACs to -5v to +8v
Range Amplifiers
Gain: 2.15k Rin: 5.22 2.10k Rin: 5.32
Vout max: 8.1v Vout min: -5.1v
needed for SWD
VDDIO
VDDCORE
VDDANA

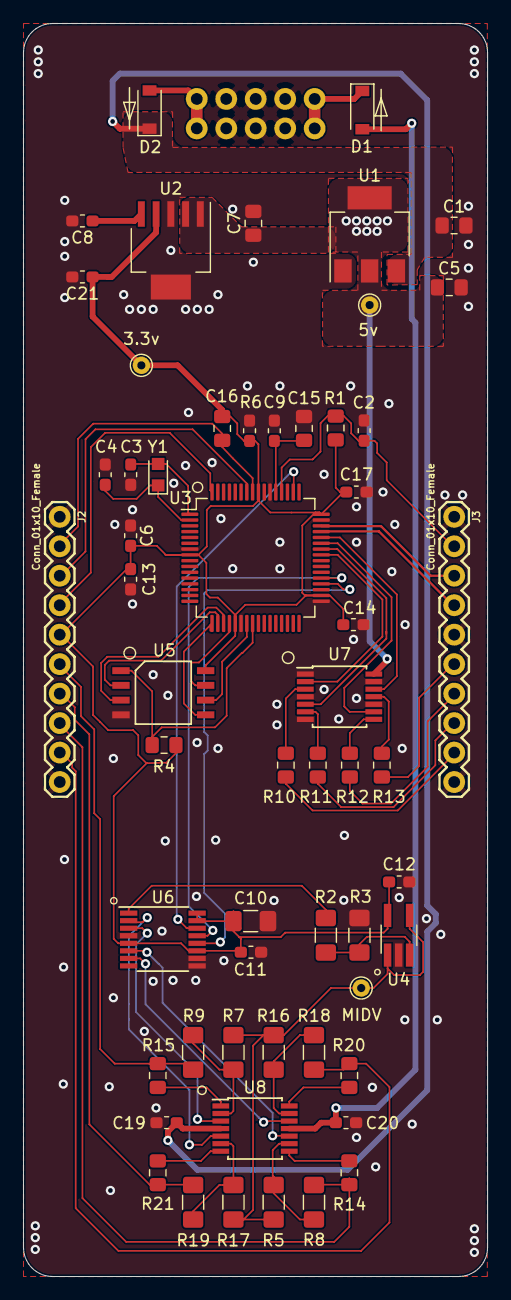
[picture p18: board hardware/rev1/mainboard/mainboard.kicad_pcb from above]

Board: 2 copper layers, 40.0 x 108.0 mm, 58 parts (1 on the bottom side), 57 nets.

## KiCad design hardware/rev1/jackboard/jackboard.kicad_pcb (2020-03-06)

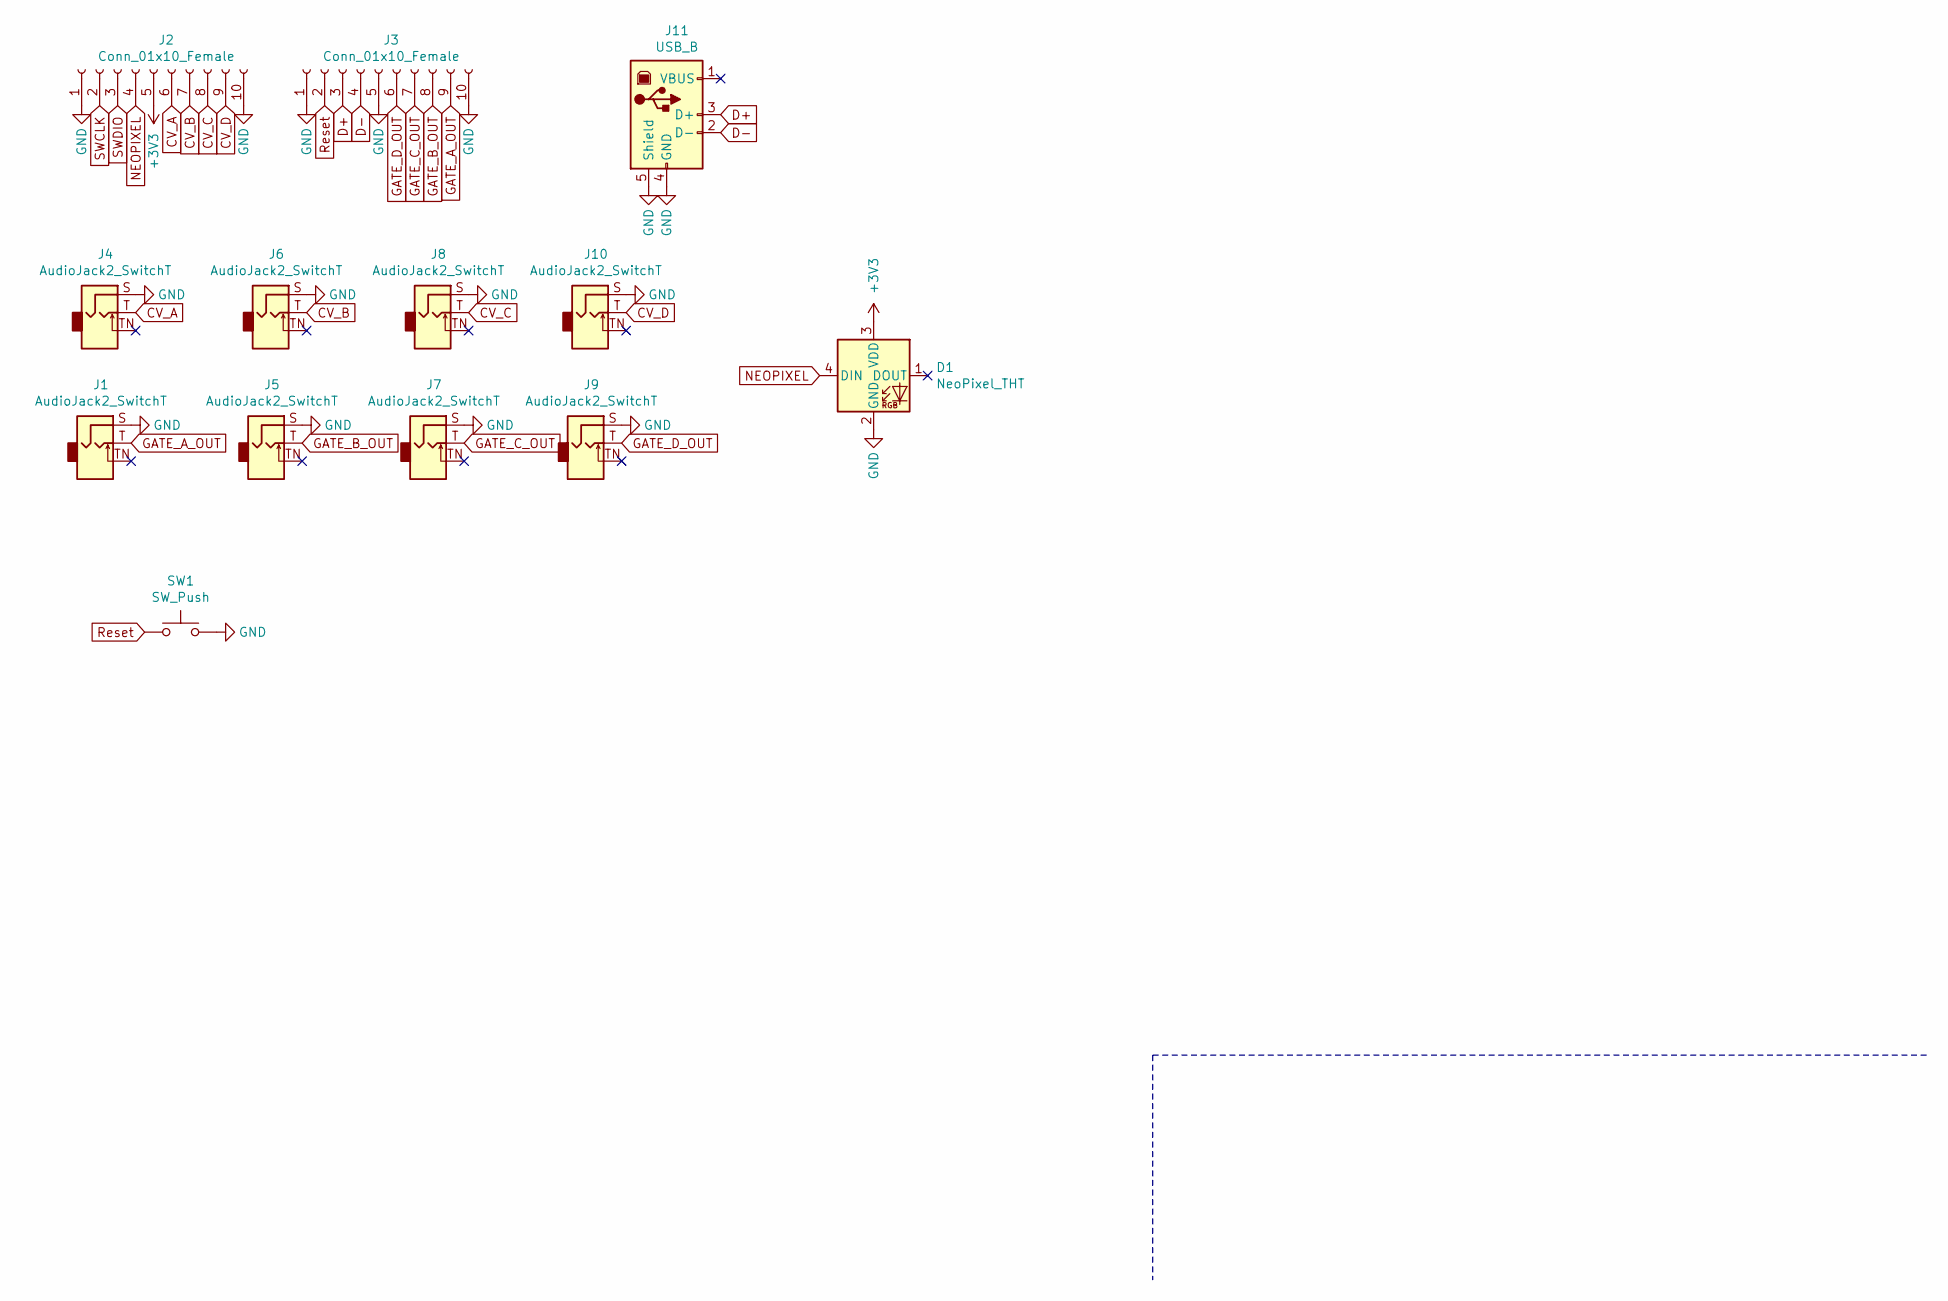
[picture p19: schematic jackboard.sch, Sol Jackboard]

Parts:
D1: NeoPixel_THT; LED_D5.0mm-4_RGB
J1, J4, J5, J6, J7, J8, J9, J10: AudioJack2_SwitchT; WQP-PJ301M-12_JACK
J2, J3: Conn_01x10_Female; 1X10_LOCK
J11: USB_B; USB_B_TE_5787834_Vertical
SW1: SW_Push; SW_PUSH_6mm

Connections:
+3V3: D1.3 (VDD), J2.5
CV_A: J2.6, J4.T
CV_B: J2.7, J6.T
CV_C: J2.8, J8.T
CV_D: J2.9, J10.T
D+: J3.3, J11.3 (D+)
D-: J3.4, J11.2 (D-)
GATE_A_OUT: J1.T, J3.9
GATE_B_OUT: J3.8, J5.T
GATE_C_OUT: J3.7, J7.T
GATE_D_OUT: J3.6, J9.T
GND: D1.2 (GND), J1.S, J2.1, J2.10, J3.1, J3.5, J3.10, J4.S, J5.S, J6.S, J7.S, J8.S, J9.S, J10.S, J11.4 (GND), J11.5 (Shield), SW1.2
NEOPIXEL: D1.4 (DIN), J2.4
Reset: J3.2, SW1.1
SWCLK: J2.2
SWDIO: J2.3

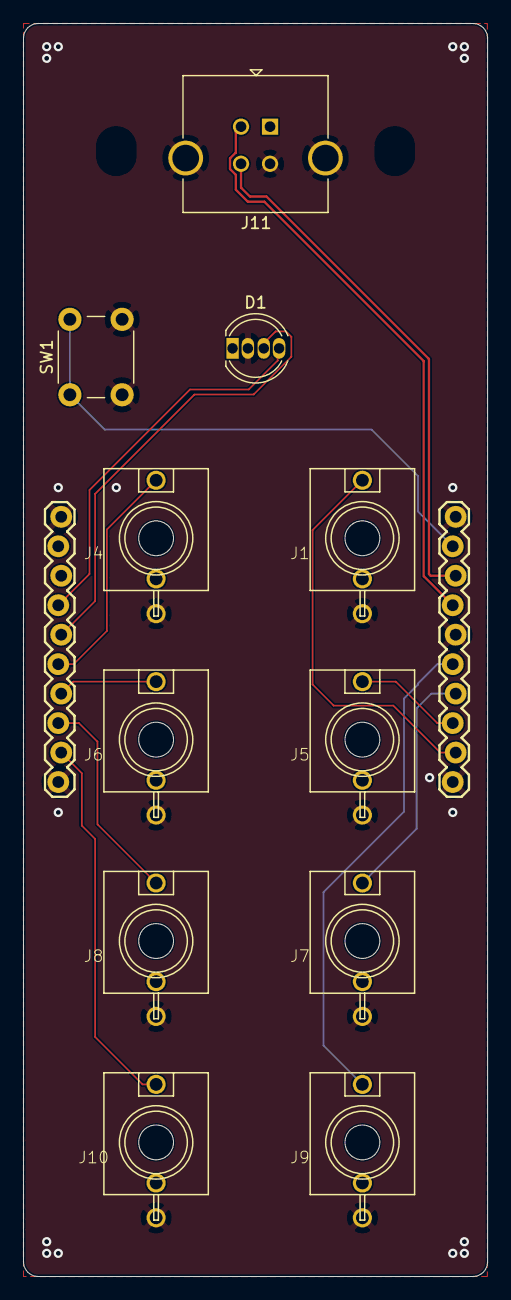
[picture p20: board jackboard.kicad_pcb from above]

Board: 2 copper layers, 40.0 x 108.0 mm, 13 parts (0 on the bottom side), 14 nets.

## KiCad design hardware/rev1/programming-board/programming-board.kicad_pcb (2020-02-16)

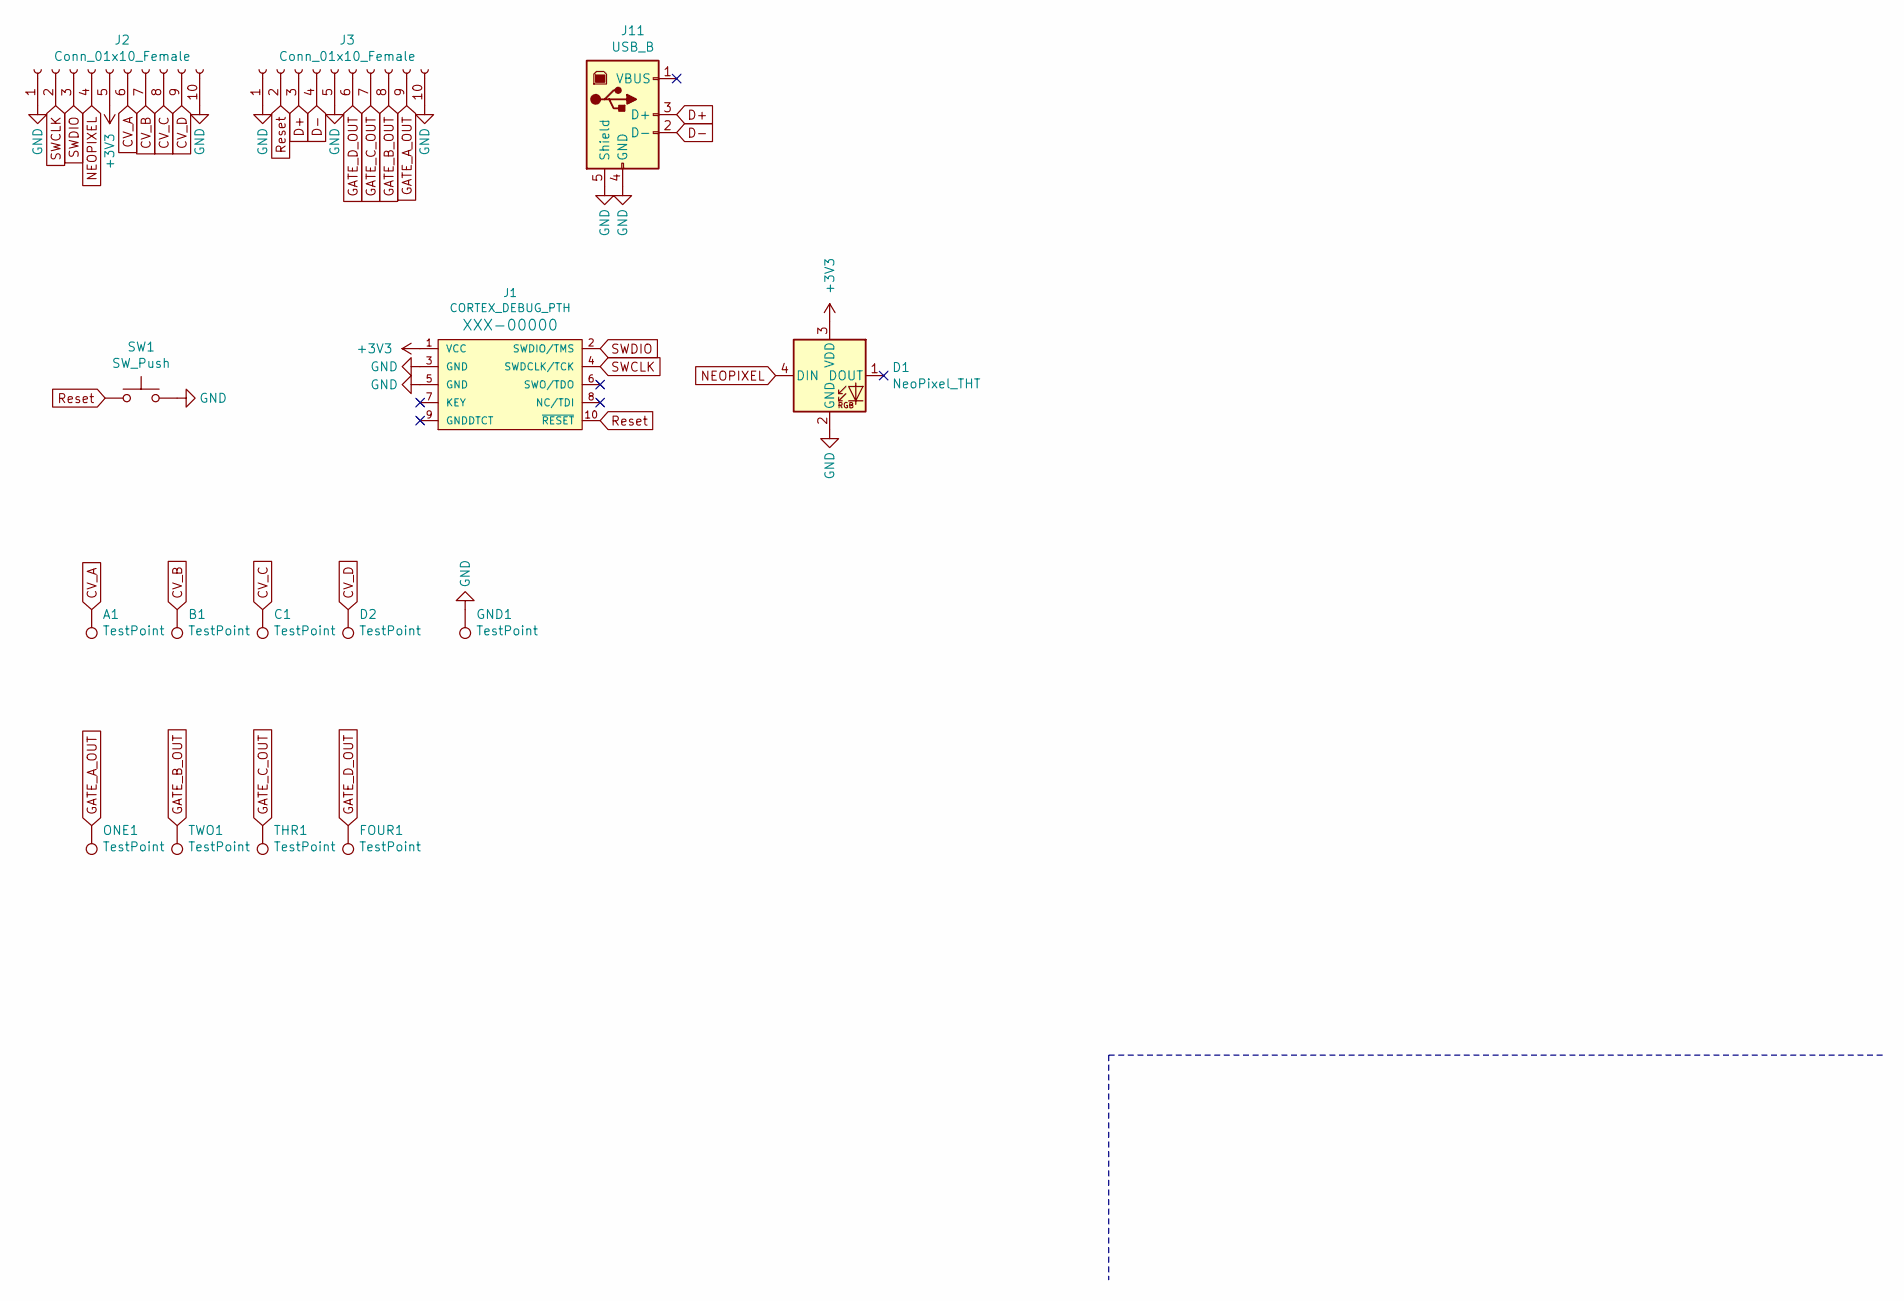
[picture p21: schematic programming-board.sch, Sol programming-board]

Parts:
A1: TestPoint; TestPoint_THTPad_D2.0mm_Drill1.0mm
B1: TestPoint; TestPoint_THTPad_D2.0mm_Drill1.0mm
C1: TestPoint; TestPoint_THTPad_D2.0mm_Drill1.0mm
D1: NeoPixel_THT; LED_D5.0mm-4_RGB
D2: TestPoint; TestPoint_THTPad_D2.0mm_Drill1.0mm
FOUR1: TestPoint; TestPoint_THTPad_D2.0mm_Drill1.0mm
GND1: TestPoint; TestPoint_THTPad_D2.0mm_Drill1.0mm
J1: CORTEX_DEBUG_PTH; 2X5-PTH-1.27MM
J2, J3: Conn_01x10_Female; 1X10_LOCK
J11: USB_B; USB_B_TE_5787834_Vertical
ONE1: TestPoint; TestPoint_THTPad_D2.0mm_Drill1.0mm
SW1: SW_Push; SW_PUSH_6mm
THR1: TestPoint; TestPoint_THTPad_D2.0mm_Drill1.0mm
TWO1: TestPoint; TestPoint_THTPad_D2.0mm_Drill1.0mm

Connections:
+3V3: D1.3 (VDD), J1.1 (VCC), J2.5
CV_A: A1.1, J2.6
CV_B: B1.1, J2.7
CV_C: C1.1, J2.8
CV_D: D2.1, J2.9
D+: J3.3, J11.3 (D+)
D-: J3.4, J11.2 (D-)
GATE_A_OUT: J3.9, ONE1.1
GATE_B_OUT: J3.8, TWO1.1
GATE_C_OUT: J3.7, THR1.1
GATE_D_OUT: FOUR1.1, J3.6
GND: D1.2 (GND), GND1.1, J1.3 (GND), J1.5 (GND), J2.1, J2.10, J3.1, J3.5, J3.10, J11.4 (GND), J11.5 (Shield), SW1.2
NEOPIXEL: D1.4 (DIN), J2.4
Reset: J1.10 (~RESET), J3.2, SW1.1
SWCLK: J1.4 (SWDCLK/TCK), J2.2
SWDIO: J1.2 (SWDIO/TMS), J2.3

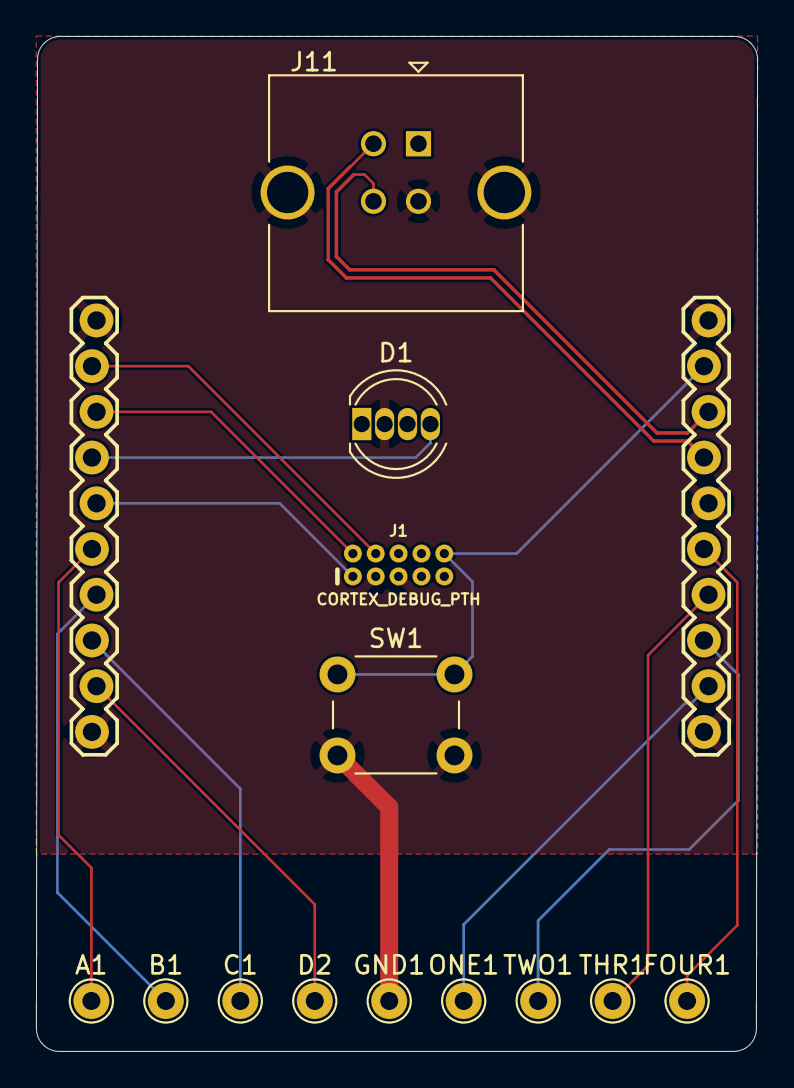
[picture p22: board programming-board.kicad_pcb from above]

Board: 2 copper layers, 40.1 x 56.4 mm, 15 parts (0 on the bottom side), 16 nets.

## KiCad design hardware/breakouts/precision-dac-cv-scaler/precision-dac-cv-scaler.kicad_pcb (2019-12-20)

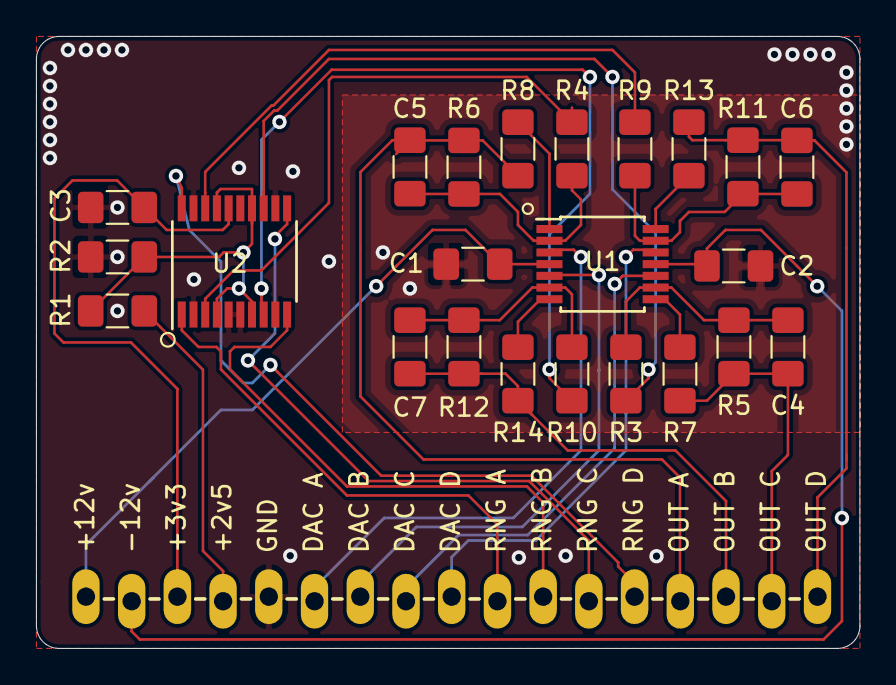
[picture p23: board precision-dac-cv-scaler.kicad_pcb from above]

Board: 2 copper layers, 45.8 x 34.0 mm, 24 parts (0 on the bottom side), 30 nets.

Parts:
C1, C2, C3: 0.1uF; C_1206_3216Metric_Pad1.42x1.75mm_HandSolder
C4, C5, C6, C7: 22pF; C_1206_3216Metric_Pad1.42x1.75mm_HandSolder
J1: CONN_20LOCK_LONGPADS; 1X20_LOCK_LONGPADS
R1: 4.70k 0.1%; R_1206_3216Metric_Pad1.42x1.75mm_HandSolder
R2: 9.1k 0.1%; R_1206_3216Metric_Pad1.42x1.75mm_HandSolder
R3, R4, R9, R10: 2.94k 0.1%; R_1206_3216Metric_Pad1.42x1.75mm_HandSolder
R5, R6, R11, R12: 8.87k 0.1%; R_1206_3216Metric_Pad1.42x1.75mm_HandSolder
R7, R8, R13, R14: 1k 0.1%; R_1206_3216Metric_Pad1.42x1.75mm_HandSolder
U1: OPA4180; TSSOP-14_4.4x5mm_P0.65mm
U2: TMUX1134; TSSOP-20_4.4x6.5mm_P0.65mm

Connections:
+2V5: J1.4, R1.1
+3V3: C3.1, J1.3, U2.16
+12V: C1.1, J1.1, U1.4
-12V: C2.2, J1.2, U1.11
DAC_A: J1.6, U1.3
DAC_B: J1.7, U1.5
DAC_C: J1.8, U1.10
DAC_D: J1.9, U1.12
GND: C1.2, C2.1, C3.2, J1.5, R2.2, U2.2, U2.5, U2.6, U2.9, U2.12, U2.19
MID_RANGE_VREF: R1.2, R2.1, U2.4, U2.7, U2.14, U2.17
unnamed: C4.2, R3.1, R5.2, U1.9
unnamed: C5.2, R4.1, R6.2, U1.2
unnamed: C6.2, R9.1, R11.2, U1.13
unnamed: C7.2, R10.1, R12.2, U1.6
unnamed: R7.2, U1.8
unnamed: R8.2, U1.1
unnamed: R13.2, U1.14
unnamed: R14.2, U1.7
OUT_A: C5.1, J1.14, R6.1, R8.1
OUT_B: C7.1, J1.15, R12.1, R14.1
OUT_C: C4.1, J1.16, R5.1, R7.1
OUT_D: C6.1, J1.17, R11.1, R13.1
RANGE_A: J1.10, U2.1
RANGE_B: J1.11, U2.10
RANGE_C: J1.12, U2.11
RANGE_D: J1.13, U2.20
RANGE_REF_A: R4.2, U2.3
RANGE_REF_B: R10.2, U2.8
RANGE_REF_C: R3.2, U2.13
RANGE_REF_D: R9.2, U2.18

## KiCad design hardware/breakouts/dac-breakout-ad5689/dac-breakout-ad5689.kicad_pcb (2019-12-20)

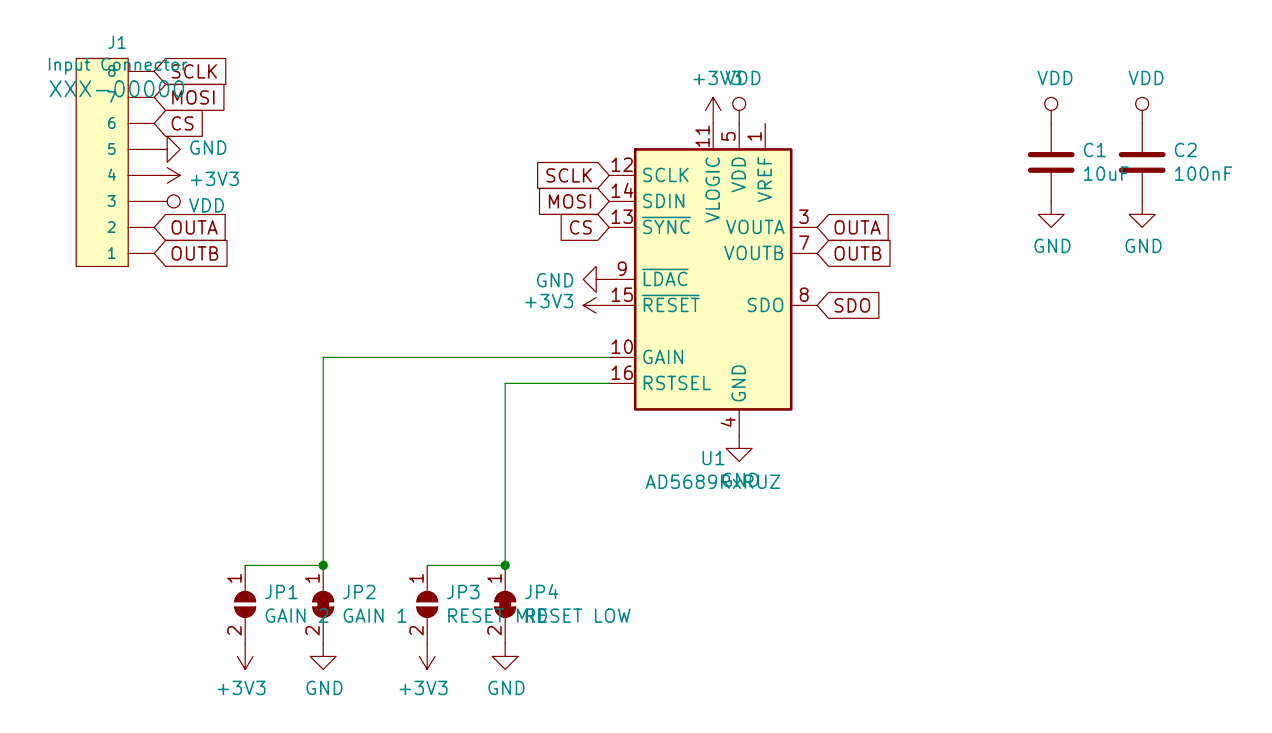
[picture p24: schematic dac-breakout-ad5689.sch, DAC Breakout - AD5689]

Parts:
C1: 10uF; C_1210_3225Metric_Pad1.42x2.65mm_HandSolder
C2: 100nF; C_1210_3225Metric_Pad1.42x2.65mm_HandSolder
J1: Input Connector; 1X08_LOCK_LONGPADS
JP1: GAIN 2; SolderJumper-2_P1.3mm_Open_Pad1.0x1.5mm
JP2: GAIN 1; SolderJumper-2_P1.3mm_Bridged_RoundedPad1.0x1.5mm
JP3: RESET MID; SolderJumper-2_P1.3mm_Open_Pad1.0x1.5mm
JP4: RESET LOW; SolderJumper-2_P1.3mm_Bridged_RoundedPad1.0x1.5mm
U1: AD5689RxRUZ; TSSOP-16_4.4x5mm_P0.65mm

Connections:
+3V3: J1.4, JP1.2 (B), JP3.2 (B), U1.11 (VLOGIC), U1.15 (~RESET)
CS: J1.6, U1.13 (~SYNC)
GND: C1.2, C2.2, J1.5, JP2.2 (B), JP4.2 (B), U1.4 (GND), U1.9 (~LDAC)
MOSI: J1.7, U1.14 (SDIN)
unnamed: JP1.1 (A), JP2.1 (A), U1.10 (GAIN)
unnamed: JP3.1 (A), JP4.1 (A), U1.16 (RSTSEL)
OUTA: J1.2, U1.3 (VOUTA)
OUTB: J1.1, U1.7 (VOUTB)
SCLK: J1.8, U1.12 (SCLK)
SDO: U1.8 (SDO)
VDD: C1.1, C2.1, J1.3, U1.5 (VDD)

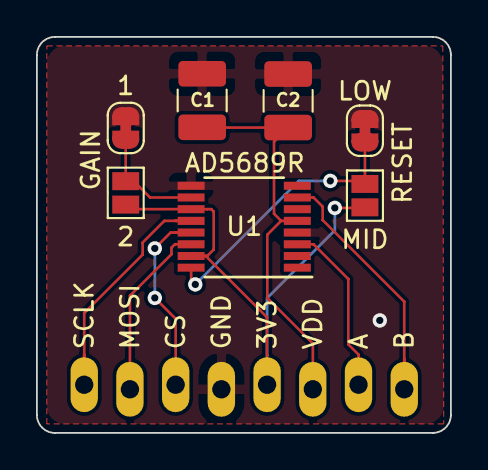
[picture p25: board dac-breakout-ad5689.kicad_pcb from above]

Board: 2 copper layers, 23.0 x 22.0 mm, 8 parts (0 on the bottom side), 10 nets.

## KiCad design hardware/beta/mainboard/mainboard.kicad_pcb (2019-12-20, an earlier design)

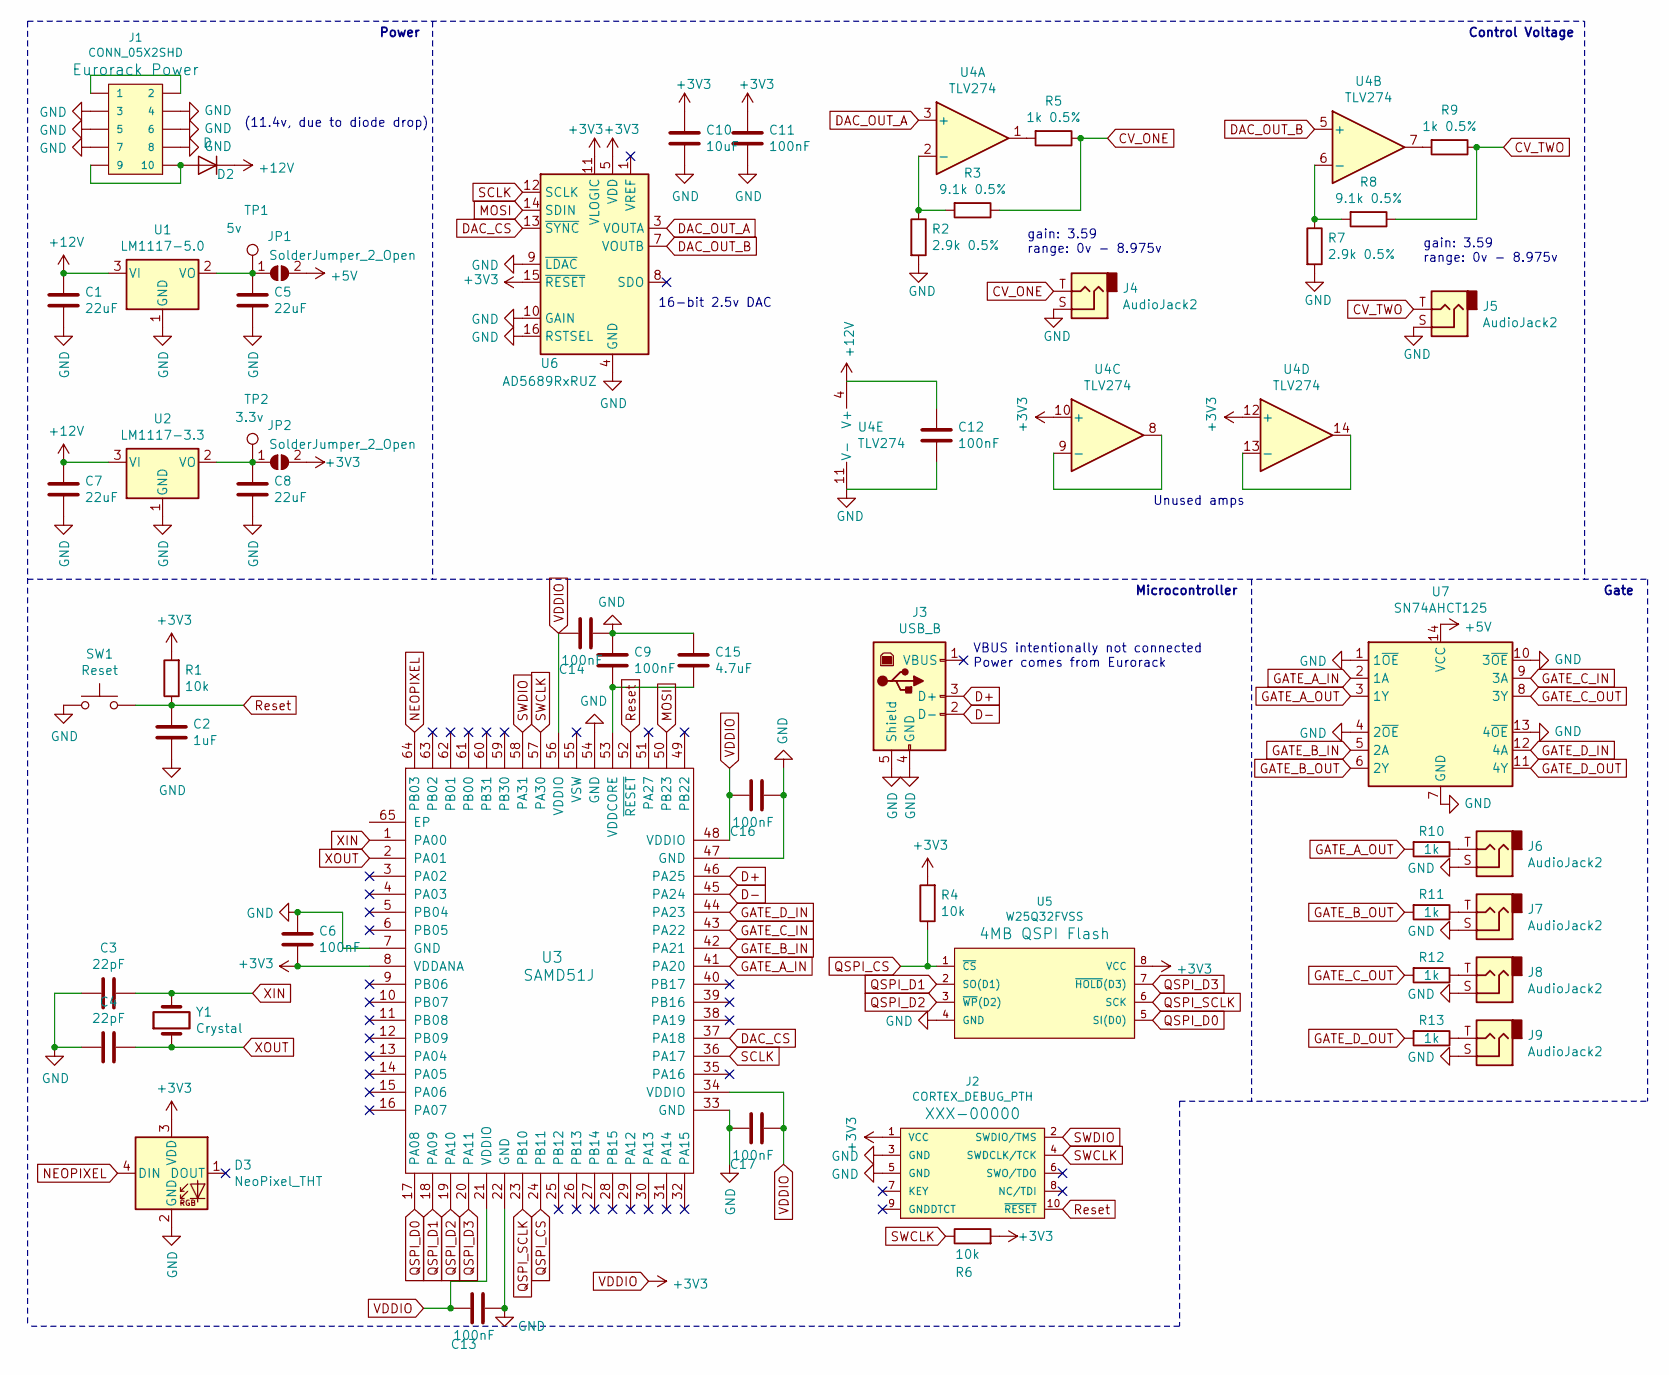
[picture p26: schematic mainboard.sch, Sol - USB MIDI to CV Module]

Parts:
C1, C5, C7, C8: 22uF; C_1206_3216Metric_Pad1.42x1.75mm_HandSolder
C2: 1uF; C_1206_3216Metric_Pad1.42x1.75mm_HandSolder
C3, C4: 22pF; C_1206_3216Metric_Pad1.42x1.75mm_HandSolder
C6, C9, C11, C12, C13, C14, C16, C17: 100nF; C_1206_3216Metric_Pad1.42x1.75mm_HandSolder
C10: 10uF; C_1206_3216Metric_Pad1.42x1.75mm_HandSolder
C15: 4.7uF; C_1206_3216Metric_Pad1.42x1.75mm_HandSolder
D2: D; D_0805_2012Metric_Pad1.15x1.40mm_HandSolder
D3: NeoPixel_THT; LED_D5.0mm-4_RGB
J1: CONN_05X2SHD; 2X5-SHROUDED
J2: CORTEX_DEBUG_PTH; 2X5-PTH-1.27MM
J3: USB_B; USB_B_TE_5787834_Vertical
J4, J5, J6, J7, J8, J9: AudioJack2; Jack_3.5mm_QingPu_WQP-PJ3010B
JP1, JP2: SolderJumper_2_Open; SolderJumper-2_P1.3mm_Open_RoundedPad1.0x1.5mm
R1, R4, R6: 10k; R_1206_3216Metric_Pad1.42x1.75mm_HandSolder
R2, R7: 2.9k 0.5%; R_1206_3216Metric_Pad1.42x1.75mm_HandSolder
R3, R8: 9.1k 0.5%; R_1206_3216Metric_Pad1.42x1.75mm_HandSolder
R5, R9: 1k 0.5%; R_1206_3216Metric_Pad1.42x1.75mm_HandSolder
R10, R11, R12, R13: 1k; R_1206_3216Metric_Pad1.42x1.75mm_HandSolder
SW1: Reset; TACTILE_SWITCH_PTH_6.0MM
TP1: 5v; TestPoint_THTPad_D1.5mm_Drill0.7mm
TP2: 3.3v; TestPoint_THTPad_D1.5mm_Drill0.7mm
U1: LM1117-5.0; SOT-223-3_TabPin2
U2: LM1117-3.3; SOT-223-3_TabPin2
U3: SAMD51J; TQFP-64_10x10mm_P0.5mm
U4: TLV274; TSSOP-14_4.4x5mm_P0.65mm
U5: W25Q32FVSS; SOIC-8
U6: AD5689RxRUZ; TSSOP-16_4.4x5mm_P0.65mm
U7: SN74AHCT125; TSSOP-14_4.4x5mm_P0.65mm
Y1: Crystal; Crystal_SMD_2012-2Pin_2.0x1.2mm_HandSoldering

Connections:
+5V: JP1.2 (B), U7.14 (VCC)
+12V: C1.1, C7.1, C12.2, D2.1 (K), U1.3 (VI), U2.3 (VI), U4.4 (V+)
CV_ONE: J4.T, R3.1, R5.1
CV_TWO: J5.T, R8.1, R9.1
D+: J3.3 (D+), U3.46 (PA25)
D-: J3.2 (D-), U3.45 (PA24)
DAC_CS: U3.37 (PA18), U6.13 (~SYNC)
DAC_OUT_A: U4.3 (+), U6.3 (VOUTA)
DAC_OUT_B: U4.5 (+), U6.7 (VOUTB)
GATE_A_IN: U3.41 (PA20), U7.2 (1A)
GATE_A_OUT: R10.2, U7.3 (1Y)
GATE_B_IN: U3.42 (PA21), U7.5 (2A)
GATE_B_OUT: R11.2, U7.6 (2Y)
GATE_C_IN: U3.43 (PA22), U7.9 (3A)
GATE_C_OUT: R12.2, U7.8 (3Y)
GATE_D_IN: U3.44 (PA23), U7.12 (4A)
GATE_D_OUT: R13.2, U7.11 (4Y)
GND: C1.2, C2.2, C3.2, C4.2, C5.2, C6.1, C7.2, C8.2, C9.1, C10.2, C11.2, C12.1, C13.2, C14.2, C15.1, C16.2, C17.1, D3.2 (GND), J1.3, J1.4, J1.5, J1.6, J1.7, J1.8, J2.3 (GND), J2.5 (GND), J3.4 (GND), J3.5 (Shield), J4.S, J5.S, J6.S, J7.S, J8.S, J9.S, R2.2, R7.2, SW1.1, U1.1 (GND), U2.1 (GND), U3.7 (GND), U3.22 (GND), U3.33 (GND), U3.47 (GND), U3.54 (GND), U4.11 (V-), U5.4 (GND), U6.4 (GND), U6.9 (~LDAC), U6.10 (GAIN), U6.16 (RSTSEL), U7.1 (1~OE), U7.4 (2~OE), U7.7 (GND), U7.10 (3~OE), U7.13 (4~OE)
MOSI: U3.50 (PB23), U6.14 (SDIN)
NEOPIXEL: D3.4 (DIN), U3.64 (PB03)
unnamed: C5.1, JP1.1 (A), TP1.1, U1.2 (VO)
unnamed: C8.1, JP2.1 (A), TP2.1, U2.2 (VO)
unnamed: C9.2, C15.2, U3.53 (VDDCORE)
unnamed: D2.2 (A), J1.9, J1.10
unnamed: J1.1, J1.2
unnamed: J6.T, R10.1
unnamed: J7.T, R11.1
unnamed: J8.T, R12.1
unnamed: J9.T, R13.1
unnamed: R2.1, R3.2, U4.2 (-)
unnamed: R5.2, U4.1
unnamed: R7.1, R8.2, U4.6 (-)
unnamed: R9.2, U4.7
unnamed: U4.8, U4.9 (-)
unnamed: U4.13 (-), U4.14
QSPI_CS: R4.1, U3.24 (PB11), U5.1 (~CS~)
QSPI_D0: U3.17 (PA08), U5.5 (SI(D0))
QSPI_D1: U3.18 (PA09), U5.2 (SO(D1))
QSPI_D2: U3.19 (PA10), U5.3 (~WP~(D2))
QSPI_D3: U3.20 (PA11), U5.7 (~HOLD~(D3))
QSPI_SCLK: U3.23 (PB10), U5.6 (SCK)
Reset: C2.1, J2.10 (~RESET), R1.1, SW1.2, U3.52 (~RESET)
SCLK: U3.36 (PA17), U6.12 (SCLK)
SWCLK: J2.4 (SWDCLK/TCK), R6.1, U3.57 (PA30)
SWDIO: J2.2 (SWDIO/TMS), U3.58 (PA31)
VDDIO: C6.2, C10.1, C11.1, C13.1, C14.1, C16.1, C17.2, D3.3 (VDD), J2.1 (VCC), JP2.2 (B), R1.2, R4.2, R6.2, U3.8 (VDDANA), U3.21 (VDDIO), U3.34 (VDDIO), U3.48 (VDDIO), U3.56 (VDDIO), U4.10 (+), U4.12 (+), U5.8 (VCC), U6.5 (VDD), U6.11 (VLOGIC), U6.15 (~RESET)
XIN: C3.1, U3.1 (PA00), Y1.2
XOUT: C4.1, U3.2 (PA01), Y1.1

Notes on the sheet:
gain: 3.59 range: 0v - 8.975v
Power
Microcontroller
Control Voltage
Gate
Unused amps
16-bit 2.5v DAC
VBUS intentionally not connected Power comes from Eurorack
(11.4v, due to diode drop)

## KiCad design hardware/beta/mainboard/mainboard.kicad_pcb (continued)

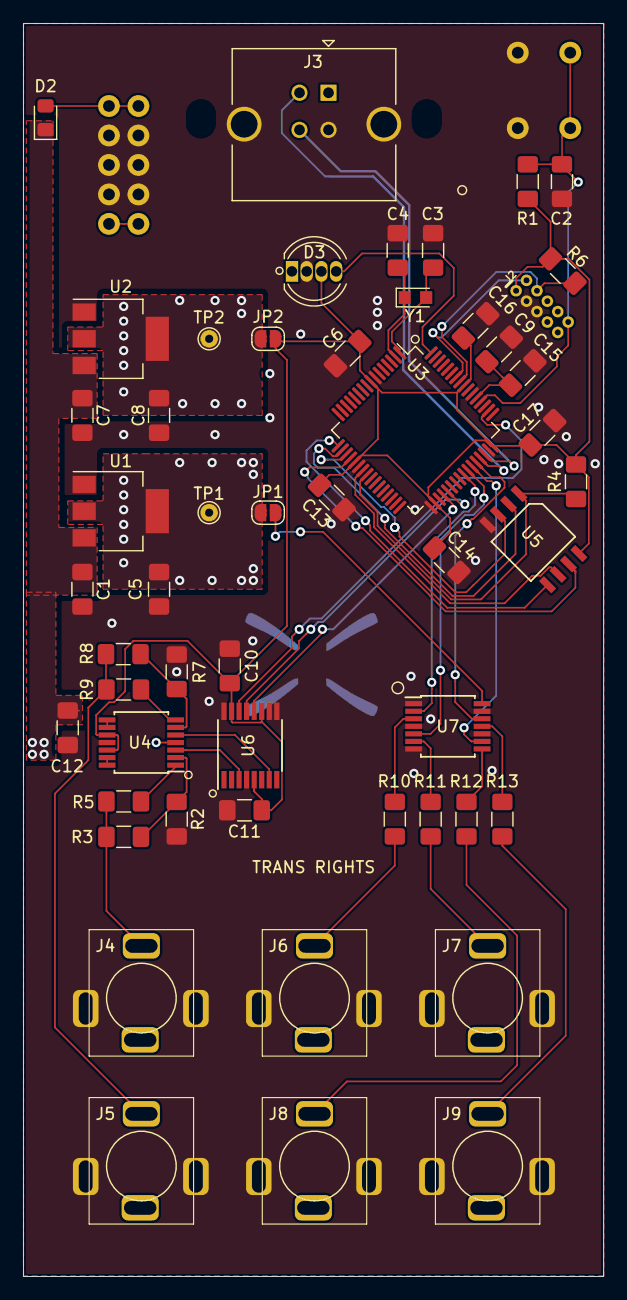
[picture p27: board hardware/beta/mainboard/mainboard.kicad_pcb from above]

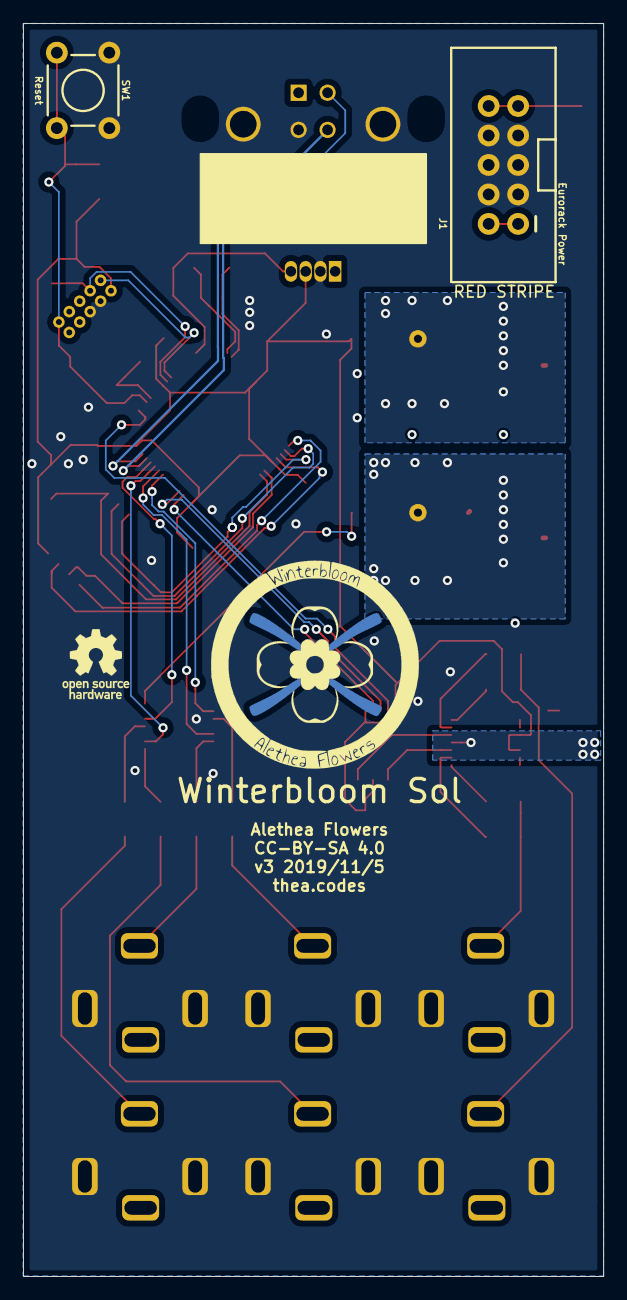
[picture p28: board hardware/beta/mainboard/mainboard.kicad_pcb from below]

Board: 2 copper layers, 50.0 x 108.0 mm, 55 parts (3 on the bottom side), 48 nets.

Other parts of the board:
Ref**: Val**; winterbloom-pcb-logo

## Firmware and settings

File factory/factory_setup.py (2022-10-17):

import os
import sys

from wintertools import fs, circuitpython, fw_fetch, jlink, uf2_to_bin
from libsol import calibrate

DEVICE_NAME = "winterbloom_sol"
JLINK_DEVICE = "ATSAMD51J20"
JLINK_SCRIPT = "scripts/flash.jlink"

ROOT_DIR = os.path.abspath(os.path.join(os.path.dirname(__file__), ".."))
FIRMWARE_DIR = os.path.join(ROOT_DIR, "firmware")
LIB_DIR = os.path.join(FIRMWARE_DIR, "lib")
EXAMPLES_DIR = os.path.join(ROOT_DIR, "examples")

FILES_TO_DOWNLOAD = {
    "https+zip://github.com/adafruit/Adafruit_CircuitPython_NeoPixel/releases/download/6.3.6/adafruit-circuitpython-neopixel-7.x-mpy-6.3.6.zip:*/lib/neopixel.mpy": "neopixel.mpy",
    "https+zip://github.com/adafruit/Adafruit_CircuitPython_BusDevice/releases/download/5.2.3/adafruit-circuitpython-busdevice-7.x-mpy-5.2.3.zip:*/lib/adafruit_bus_device/*": "adafruit_bus_device/"
}

FILES_TO_DEPLOY = {
    fs.cache_path("neopixel.mpy"): "lib",
    fs.cache_path("adafruit_bus_device"): "lib",
    os.path.join(FIRMWARE_DIR, "winterbloom_sol"): "lib",
    os.path.join(FIRMWARE_DIR, "LICENSE"): ".",
    os.path.join(FIRMWARE_DIR, "README.HTM"): ".",
    os.path.join(LIB_DIR, "winterbloom_ad_dacs/winterbloom_ad_dacs"): "lib",
    os.path.join(LIB_DIR, "winterbloom_voltageio/winterbloom_voltageio.py"): "lib",
    os.path.join(LIB_DIR, "winterbloom_smolmidi/winterbloom_smolmidi.py"): "lib",
    EXAMPLES_DIR: ".",
    os.path.join(EXAMPLES_DIR, "1_default.py"): "code.py",
}


def program_firmware():
    print("========== PROGRAMMING FIRMWARE ==========")

    fw_fetch.latest_bootloader(DEVICE_NAME)
    firmware_path = fw_fetch.latest_circuitpython(DEVICE_NAME)

    uf2_to_bin.with_file(firmware_path)

    jlink.run(JLINK_DEVICE, JLINK_SCRIPT)


def deploy_circuitpython_code(destination=None, publish_only=False):
    print("========== DEPLOYING CODE ==========")

    if not destination:
        print("Waiting for CIRCUITPY drive...")
        destination = fs.wait_for_drive("CIRCUITPY")

    if not publish_only:
        print("Forcing device into repl (workaround for CircuitPython issue #3986)")
        circuitpython.force_into_repl(calibrate.USB_DEVICE_ID)

    print("Cleaning temporary files from src directories...")
    fs.clean_pycache(FIRMWARE_DIR)
    fs.clean_pycache(EXAMPLES_DIR)
    print("Downloading files to cache...")
    fs.download_files_to_cache(FILES_TO_DOWNLOAD)
    print("Copying files...")
    fs.deploy_files(FILES_TO_DEPLOY, destination)

    if not publish_only:
        print("Done copying files, resetting...")
        circuitpython.reset_via_serial(calibrate.USB_DEVICE_ID)

    print("Done!")


def run_calibration():
    print("========== CALIBRATION & TEST ==========")
    calibrate.main()


def main():
    if len(sys.argv) > 1 and sys.argv[1] == "publish":
        deploy_circuitpython_code("distribution", publish_only=True)
        return

    try:
        circuitpython_drive = fs.find_drive_by_name("CIRCUITPY")
    except:
        circuitpython_drive = None

    if not circuitpython_drive:
        program_firmware()

    if circuitpython_drive and os.path.exists(
        os.path.join(circuitpython_drive, "code.py")
    ):
        if input("redeploy code? y/n: ").strip() == "y":
            deploy_circuitpython_code()
    else:
        deploy_circuitpython_code()

    if not circuitpython_drive or not os.path.exists(
        os.path.join(circuitpython_drive, "calibration.py")
    ):
        run_calibration()
    elif input("recalibrate? y/n: ").strip() == "y":
        run_calibration()


if __name__ == "__main__":
    main()

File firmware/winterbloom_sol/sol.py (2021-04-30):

# The MIT License (MIT)
#
# Copyright (c) 2019 Alethea Flowers for Winterbloom
#
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
import time

import board
import digitalio
import micropython
import neopixel
import usb_midi
import winterbloom_smolmidi as smolmidi
import winterbloom_voltageio as voltageio
from winterbloom_ad_dacs import ad5686, ad5689
from winterbloom_sol import _calibration, _midi_ext, _utils, trigger


class State:
    """
    Tracks the state of MIDI input and provides easy access to common midi
    parameters.
    """

    def __init__(self):
        self.notes = {}
        self.message = None
        self.velocity = 0
        self.pitch_bend = 0
        self.pressure = 0
        self._cc = bytearray(128)
        self.playing = False
        self.clock = 0
        self.clock_frequency = 0

    @property
    @micropython.native
    def note(self):
        return self.latest_note

    @property
    @micropython.native
    def latest_note(self):
        if not self.notes:
            return None

        latest_note = None
        latest_time = 0
        for note, note_time in self.notes.items():
            if latest_time == 0 or note_time > latest_time:
                latest_note = note
                latest_time = note_time

        return latest_note

    @property
    @micropython.native
    def oldest_note(self):
        if not self.notes:
            return None

        oldest_note = None
        oldest_time = 0
        for note, note_time in self.notes.items():
            if oldest_time == 0 or note_time < oldest_time:
                oldest_note = note
                oldest_time = note_time

        return oldest_note

    @property
    @micropython.native
    def highest_note(self):
        if not self.notes:
            return None

        highest_note = 0
        for note in self.notes.keys():
            if highest_note == 0 or note > highest_note:
                highest_note = note

        return highest_note

    @property
    @micropython.native
    def lowest_note(self):
        if not self.notes:
            return None

        lowest_note = 0
        for note in self.notes.keys():
            if lowest_note == 0 or note < lowest_note:
                lowest_note = note

        return lowest_note

    @micropython.native
    def cc(self, number):
        return self._cc[number] / 127.0

    @micropython.native
    def copy_from(self, other):
        self.notes = other.notes.copy()
        self.message = other.message
        self.velocity = other.velocity
        self.pitch_bend = other.pitch_bend
        self.playing = other.playing
        self.clock = other.clock
        self._cc[:] = other._cc[:]


class StatusLED:
    def __init__(self):
        self._led = neopixel.NeoPixel(board.NEOPIXEL, 1, pixel_order=(0, 1, 2))
        self._led.brightness = 0.1
        self._led[0] = (0, 255, 255)
        self._hue = 0
        self._hue_rgb = (0, 255, 255)
        self._pulse_time = None

    @property
    def hue(self):
        return self._hue

    @hue.setter
    def hue(self, hue):
        self._hue = hue
        self._led[0] = self._hue_rgb = _utils.color_wheel(self._hue)

    def spin(self):
        self.hue += 5

    def pulse(self):
        self._pulse_time = time.monotonic_ns()
        self._led[0] = (255, 255, 255)

    @micropython.native
    def step(self):
        if self._pulse_time is None:
            return

        pulse_dt = min(
            ((time.monotonic_ns() - self._pulse_time) / 1000000000) / 0.2, 1.0
        )
        self._led[0] = (
            int(_utils.lerp(255, self._hue_rgb[0], pulse_dt)),
            int(_utils.lerp(255, self._hue_rgb[1], pulse_dt)),
            int(_utils.lerp(255, self._hue_rgb[2], pulse_dt)),
        )

        if pulse_dt == 1.0:
            self._pulse_time = None


class Outputs:
    """Manages all of the outputs for the Sol board and provides
    easy access to set them."""

    def __init__(self):
        if _utils.is_beta():
            dac_driver = ad5689
            # 5689 is calibrated from nominal values.
            calibration = _calibration.beta_nominal_calibration()
        else:
            dac_driver = ad5686
            # 5686 is externally calibrated.
            calibration = _calibration.load_calibration()

        self._dac = dac_driver.create_from_pins(cs=board.DAC_CS)
        self._dac.soft_reset()

        self._cv_a = voltageio.VoltageOut(self._dac.a)
        self._cv_a.direct_calibration(calibration["a"])
        self._cv_b = voltageio.VoltageOut(self._dac.b)
        self._cv_b.direct_calibration(calibration["b"])

        # 5686 has 4 channels.
        if dac_driver == ad5686:
            self._cv_c = voltageio.VoltageOut(self._dac.c)
            self._cv_c.direct_calibration(calibration["c"])
            self._cv_d = voltageio.VoltageOut(self._dac.d)
            self._cv_d.direct_calibration(calibration["d"])

        self._gate_1 = digitalio.DigitalInOut(board.G1)
        self._gate_1.direction = digitalio.Direction.OUTPUT
        self._gate_2 = digitalio.DigitalInOut(board.G2)
        self._gate_2.direction = digitalio.Direction.OUTPUT
        self._gate_3 = digitalio.DigitalInOut(board.G3)
        self._gate_3.direction = digitalio.Direction.OUTPUT
        self._gate_4 = digitalio.DigitalInOut(board.G4)
        self._gate_4.direction = digitalio.Direction.OUTPUT

        self._gate_1_trigger = trigger.Trigger(self._gate_1)
        self._gate_2_trigger = trigger.Trigger(self._gate_2)
        self._gate_3_trigger = trigger.Trigger(self._gate_3)
        self._gate_4_trigger = trigger.Trigger(self._gate_4)
        self._gate_1_retrigger = trigger.Retrigger(self._gate_1)
        self._gate_2_retrigger = trigger.Retrigger(self._gate_2)
        self._gate_3_retrigger = trigger.Retrigger(self._gate_3)
        self._gate_4_retrigger = trigger.Retrigger(self._gate_4)

        self.led = StatusLED()
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

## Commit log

2019-10-29 Update voltageio
2019-10-31 Add support for Note On with 0 velocity
2019-11-01 Update sample
2019-11-02 Small fixes from testing MIDI clock
    [helpers.py, sol.py]
2019-11-04 Re-blacken, fix isort
    [.isort.cfg]
2019-11-25 Switch ADSR to monotonic_ns
2019-12-03 Add assembly test program
2019-12-05 Move status LED to the Outputs class
2019-12-20 Move software into the firmware directory to prepare for hardware files
    [.isort.cfg]
2019-12-20 Add beta mainboard hardware design files
    [mainboard-B_Cu.gbr, mainboard-B_Mask.gbr, mainboard-B_Paste.gbr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]
2019-12-20 Add beta panel hardware design files
    [panel-B_Cu.gbr, panel-B_Mask.gbr, panel-B_SilkS.gbr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]
2019-12-20 Add breakouts
    [dac-breakout-ad5689-B_Cu.gbr, dac-breakout-ad5689-B_Mask.gbr, dac-breakout-ad5689-B_SilkS.gbr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]
2019-12-21 Update the deploy script to prepare a bundle instead of uploading directly to the device
2020-01-11 Add first run at mainboard for rev1
    [mainboard-1-9.kicad_pcb, mainboard.kicad_pcb, mainboard.sch]
2020-01-11 Remove old revision of mainboard
    [mainboard-1-9.kicad_pcb]
2020-01-12 Switch 3v3 regulator to TPS796
    [mainboard.kicad_pcb, mainboard.sch]
2020-01-13 Replace voltage reference buffer with OPA388
    [mainboard.kicad_pcb, mainboard.sch]
2020-01-13 Re-route the +12v trace and do a bunch of ground stitching
    [mainboard.kicad_pcb]
2020-01-14 Finish up mainboard - place silkscreen, add branding, etc.
    [mainboard.kicad_pcb]
2020-01-15 Fix some component sizes
    [mainboard.kicad_pcb, mainboard.sch]
2020-01-15 Move to the AD5686R, drop the TMUX
    [mainboard.kicad_pcb, mainboard.sch, soic-8.step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]
2020-01-15 Update some cap sizes
    [mainboard.kicad_pcb, mainboard.sch]
2020-01-15 Assign MPNs to all symbols
    [mainboard.kicad_pcb, mainboard.sch]
2020-01-15 Assigning more MPNs
    [mainboard.sch]
2020-01-15 Add PDF of schematic
2020-01-19 Add basic, unfinished jackboard
    [User Library-PJ301M-12 Thonkiconn v0_2.STEP, c-5787834-1-c-3d.step, jackboard.kicad_pcb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]
2020-01-19 Add basic, unfinished panel
    [panel-B_Cu.gbr, panel-B_Mask.gbr, panel-B_SilkS.gbr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]
2020-01-20 Add programming board
    [User Library-PJ301M-12 Thonkiconn v0_2.STEP, c-5787834-1-c-3d.step, programming-board.kicad_pcb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]
2020-02-16 Update voltagio
    [programming-board.kicad_pcb]
2020-02-29 Add calibration script, make Sol read from calibration
2020-03-02 Add missing outputs to Sol
    [sol.py]
2020-03-02 Fix cv c and d outputs
    [sol.py]
2020-03-03 Wrap up prototype jackboard
    [jackboard.kicad_pcb, jackboard.sch]
2020-03-04 Add blank panel
    [jackboard.kicad_pcb, jackboard.step, panel.kicad_pcb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]
2020-03-05 Add reset to LFOs
    [lfo.py]
2020-03-06 Add some missing 3d moels
    [eurorack-power.step, jackboard.kicad_pcb, mainboard.kicad_pcb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]
2020-03-06 Save and load calibration from NVM, restore beta board support
2020-03-07 Add random sample
2020-03-12 Add experimental calibration restorer
2020-03-12 Add calibration rescure procedure to firmware
2020-04-03 Update panel and gerbers
    [panel-B_Cu.gbr, panel-B_Mask.gbr, panel-B_SilkS.gbr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]
2020-04-10 Update panel with new logo
    [panel.kicad_pcb]
2020-04-24 Update all gerbes for latest PCB revisions
    [mainboard.kicad_pcb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]
2020-05-31 Alias aftertouch to state.pressure
2020-06-19 Fix decay phase for re-started envelopes
    [adsr.py]
2020-10-03 Remove micropython.native in helpers, as it seems to be buggy
    [helpers.py]
2020-10-27 Refine the factory setup script a little more: automatically detect when drvives are available and detect when the correct DAC channel is connected to the multimeter.
    [calibrate.py, factory_setup.py]
2020-10-28 Remove some debug prints, make deploy_files output nicer
2020-12-12 Update PDF of schematic and add git pre-commit hook to make sure it stays up-to-date
    [mainboard.sch]
2021-01-29 docs: Add link to Liz Clark's video on Raspberry Pi MIDI host.
2021-04-04 Fixup factory setup script to work with latest wintertools
    [factory_setup.py]
2021-04-30 factory: fix publish command
    [factory_setup.py]
2021-04-30 firmware: fix should_trigger_clock() to only trigger when a clock message is received, fixing #7
    [helpers.py, sol.py]
2022-10-17 Fix SPIDevice error in new versions of CircuitPython and Adafruit_Bus_Device
    [factory_setup.py]
